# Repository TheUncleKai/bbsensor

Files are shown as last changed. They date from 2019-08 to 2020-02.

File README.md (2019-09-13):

# bbsensor
BBQ Sensor

The 8 is a simple temperature monitor intended for BBQ/Smoker. It has 8 inlets that can be used with PTC or Pt100 probes. The BBSensor is run by a ESP8266 Microcontroller (NodeMCU Lua Lolin V3 Modul). The temperature can be delivered either via the display or network.

Front view
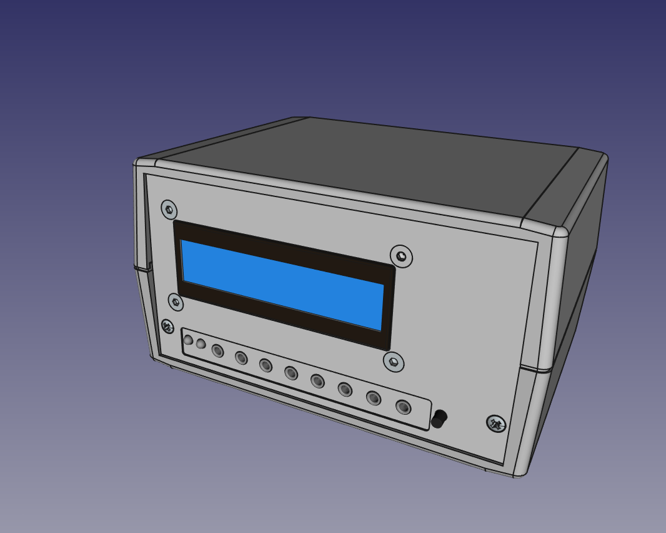
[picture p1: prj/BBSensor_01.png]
Main View


Back view
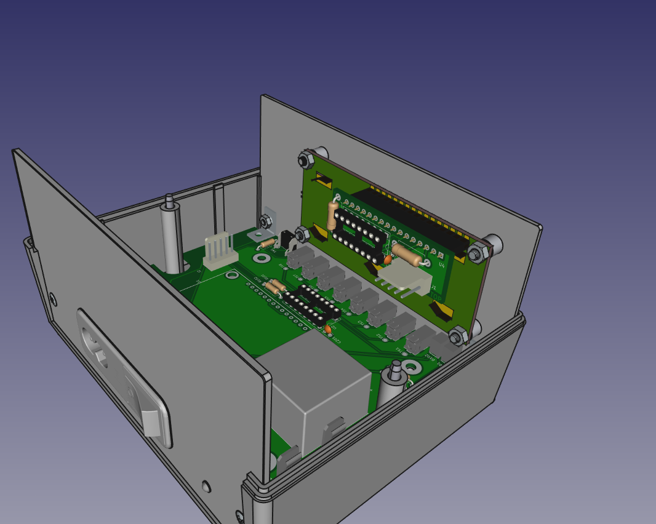
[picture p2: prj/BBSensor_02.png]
Back View


Top view
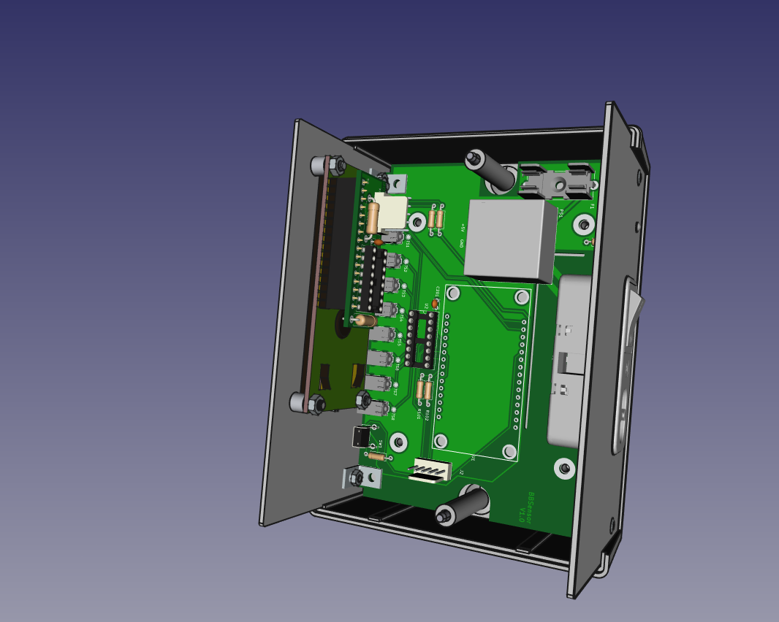
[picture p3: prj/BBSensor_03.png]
Top View


[view1]: prj/BBSensor_01.png
[view2]: prj/BBSensor_02.png
[view3]: prj/BBSensor_03.png

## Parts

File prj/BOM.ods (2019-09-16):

Project | Sourced | Placed | References | Value | Footprint | Quantity | Description | Quantity | Hersteller | Lfd. | Mouser | Price | Sum
 |  |  | R150, R151 | 140 | R_Axial_DIN0207_L6.3mm_D2.5mm_P10.16mm_Horizontal | 2 | Trimmer Resistors - Through Hole 3/8IN 500 OHM Sealed Horizontal Adjust | 12 | BOURNS | 3296Z-1-501LF | 652-3296Z-1-501LF | 2,170 € | 26,040 €
 |  |  | R8, R10 | 200 | R_Axial_DIN0207_L6.3mm_D2.5mm_P10.16mm_Horizontal | 2 | Trimmer Resistors - Through Hole 3/8" 1Mohms Sealed Horizontal Adjust | 12 | BOURNS | 3296Z-1-105LF | 652-3296Z-1-105LF | 2,170 € | 26,040 €
 |  |  | R1 | 220 | R_Axial_DIN0207_L6.3mm_D2.5mm_P10.16mm_Horizontal | 1 | Multilayer Ceramic Capacitors MLCC - Leaded 0.1uF 50volts 10% X7R 2.5mm LS | 0 | VISHAY | K104K15X7RF53L2 | 594-K104K15X7RF53L2 | 0,153 € | 0,000 €
 |  |  | R301 | 220 | R_Axial_DIN0411_L9.9mm_D3.6mm_P12.70mm_Horizontal | 1 | Analog to Digital Converters - ADC 12-bit SPI 8 Chl | 0 | MICROCHIP | MCP3208-CI/P | 579-MCP3208CIP | 3,220 € | 0,000 €
 |  |  | R2 | 300 | Potentiometer_Bourns_3296Z_Horizontal | 1 | Counter Shift Registers Tri-State 8-Bit | 0 | TI | SN74HC595N | 595-SN74HC595N | 0,477 € | 0,000 €
 |  |  | R1 | 405 | Potentiometer_Bourns_3296Z_Horizontal | 1 | Operational Amplifiers - Op Amps Single-Supply Rail-to-Rail | 6 | TI | OPA2340PAG4 | 595-OPA2340PA | 4,190 € | 25,140 €
 |  |  | R9 | 470 | Potentiometer_Bourns_3296Z_Horizontal | 1 | IC & Component Sockets STANDRD SOLDER TAIL DIP SOCKET (8 Pos) | 0 | Mill-Max | 115-47-308-41-001000 | 575-1154730841001000 | 0,414 € | 0,000 €
 |  |  | R2 | 100k | R_Axial_DIN0207_L6.3mm_D2.5mm_P10.16mm_Horizontal | 1 | IC & Component Sockets STANDRD SOLDER TAIL DIP SOCKET (16 Pos) | 0 | Mill-Max | 123-47-316-41-001000 | 575-1234731641001000 | 1,610 € | 0,000 €
 |  |  | C1 | 100n | C_Disc_D3.0mm_W2.0mm_P2.50mm | 1 | Fixed Terminal Blocks 3P 2.54mm 90DEG | 6 | PHOENIX | 1725669 | 651-1725669 | 2,230 € | 13,380 €
 |  |  | C201 | 100n | C_Disc_D3.4mm_W2.1mm_P2.50mm | 1 | Fixed Terminal Blocks 2P 2.54mm 90DEG | 6 | PHOENIX | 1725656 | 651-1725656 | 1,490 € | 8,940 €
 |  |  | C301 | 100n | C_Disc_D3.4mm_W2.1mm_P2.50mm | 1 | Headers & Wire Housings VERT PCB HDR 5P GOLD FRICTION LOCK | 0 | MOLEX | 22-11-2052 | 538-22-11-2052 | 0,747 € | 0,000 €
 |  |  | R1, R3 | 10k | R_Axial_DIN0207_L6.3mm_D2.5mm_P10.16mm_Horizontal | 2 | Headers & Wire Housings HSG 5P W/RAMP/RIBS | 0 | MOLEX | 22-01-3057 | 538-22-01-3057 | 0,234 € | 0,000 €
 |  |  | RV1 | 10k | Potentiometer_Bourns_3296Z_Horizontal | 1 | Headers & Wire Housings CRIMP TERM 22-30 TIN | 0 | MOLEX | 08-50-0114 | 538-08-50-0114 | 0,153 € | 0,000 €
 |  |  | R5, R6 | 10k | R_Axial_DIN0207_L6.3mm_D2.5mm_P10.16mm_Horizontal | 2 | Fuse Holder FUSE-HOLDER OGN | 0 | SCHURTER | 0031.8211 | 693-0031.8211 | 0,810 € | 0,000 €
 |  |  | R101 | 1k | R_Axial_DIN0207_L6.3mm_D2.5mm_P10.16mm_Horizontal | 1 | AC Power Entry Modules 2.5A C8 INLET PCB MT | 2 | SCHURTER | CMF1.1111.12 | 693-CMF1.1111.12 | 7,780 € | 15,560 €
 |  |  | R302 | 2k | R_Axial_DIN0411_L9.9mm_D3.6mm_P12.70mm_Horizontal | 1 | LED Circuit Board Indicators RED DIFFUSED RIGHT ANGLE | 16 | CML | 5600F1 | 607-5600F1 | 0,648 € | 10,368 €
 |  |  | R11 | 2k | R_Axial_DIN0207_L6.3mm_D2.5mm_P10.16mm_Horizontal | 1 | LED Circuit Board Indicators GREEN DIFFUSED RIGHT ANGLE | 16 | CML | 5600F5 | 607-5600F5 | 0,648 € | 10,368 €
 |  |  | R102, R153 | 2k2 | R_Axial_DIN0207_L6.3mm_D2.5mm_P10.16mm_Horizontal | 2 | Tactile Switches SWITCH TACTILE | 20 | C&K | PTS645VL83-2LFS | 611-PTS645VL832 | 0,279 € | 5,580 €
 |  |  | R4 | 2k2 | R_Axial_DIN0207_L6.3mm_D2.5mm_P10.16mm_Horizontal | 1 | Display Development Tools 16x2 Black on Green Char LCD w Backlight | 0 | MIDAS | MC21605C6W-SPTLYI-V2 | 992-LCD-16X2Y | 12,020 € | 0,000 €
 |  |  | R7 | 4k7 | R_Axial_DIN0207_L6.3mm_D2.5mm_P10.16mm_Horizontal | 1 | Slide Switches 3.5mm SP3T Vertical 2mm travel | 10 | ALPS | SSSS211900 | 688-SSSS211900 | 2,260 € | 22,600 €
 |  |  | U3 | 74HC595 | DIP-16_W7.62mm_Socket | 1 | AC/DC Power Modules 5W 12Vdc 416mA AC/DC Power module | 2 | TRACOPOWER | TMPS 05-112 | 495-TMPS05-112 | 16,380 € | 32,760 €
 |  |  | TH1, TH2, TH3, TH4, TH5, TH6, TH7, TH8 | AudioJack3 | LUMBERG_1501_05 | 8 |  |  | LUMBERG | 1501 05
 |  |  | J1 | Conn_01x03 | PinHeader_1x03_P2.54mm_Vertical | 1 |  |  |  |  |  |  | 196,776 €
 |  |  | J1 | Conn_01x03 | PinHeader_1x03_P2.54mm_Vertical | 1
 |  |  | J1 | Conn_01x05 | Molex_KK256_Pin_Header_Straight_1x05 | 1
 |  |  | J2 | Display | Molex_KK256_Pin_Header_Straight_1x05 | 1
 |  |  | U1 | ESP8266-12E_NodeMCU_Lolin | ESP8266-12E_NodeMCU_Lolin | 1
 |  |  | F1 | Fuse | Fuse_holder_20x5_22.5 | 1
 |  |  | D102 | GREEN | 5600F | 1
 |  |  | U4 | HD44780 | PinSocket_1x16_P2.54mm_Vertical | 1
 |  |  | U2 | MCP3208 | DIP-16_W7.62mm_Socket | 1
 |  |  | ~, ~, ~, ~ | Mounting_Bracket_L10_W7_M3 | Mounting_Bracket_L10_W7_M3 | 4
 |  |  | ~, ~ | MountingHole_2.7mm_M2.5 | MountingHole_2.7mm_M2.5 | 2
 |  |  | U1, U2 | OPA2340 | DIP-8_W7.62mm_Socket | 2
 |  |  | D1 | POWER | 5600F | 1
 |  |  | R3 | PT100 | TerminalBlock_Pheonix_MPT-2.54mm_2pol | 1
 |  |  | D101 | RED | 5600F | 1
 |  |  | J1 | Schurter_CMF1 | CMF1_Offset | 1
 |  |  | SW1 | SW_Push | SW_Tactile_SPST_Angled_PTS645Vx83-2LFS | 1
 |  |  | SW1 | SW_SP3T | ALPS_SSSS211900 | 1
 |  |  | TH1 | Thermistor_PTC | PinHeader_1x02_P2.54mm_Vertical | 1
 |  |  | PS1 | TMPS_05 | Traco_TMPS_05 | 1

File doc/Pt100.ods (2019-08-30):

Nennwiderstand: | 100 | Ohm | R0 |  | Über 0°C: | 0,003908300000000 | a
 |  |  |  |  |  | -0,000000577500000 | b | über 0°C: R=R0*(1+a*T+b*T^2) a= 3,9083*10^-3 /K b= -5,775*10^-7 /K^2 Unter 0°C: R=R0*(1+a*T+b*T^2+c*(T-100)*T^3) a= 3,9083*10^-3 b= -5,775*10^-7 c= -4,183*10^-12
Untere Spannung Ua0: | 0 | V | Umin
Obere Spannung (Ua100): | 5 | V | Umax |  | Unter 0°C: | -0,000000000004183 | c
Minimale Temperatur: | 0 | °C | Tmin
Maximale Temperatur: | 500 | °C | Tmax |  | 150
Rmin: | 100,00 | Ohm | Rmin
Rmax: | 280,98 | Ohm | Rmax |  | 157,33
Uref: | 5 | V | Uref
Messstrom: | 1 | mA | I
dU0: | 0,100 | V | dUmin
dU100: | 0,281 | V | dUmax
R2: | 300 | Ohm | R2
R4: | 2200 | Ohm | R4
U1: | 2,5 | V
k2: | 1,0825 |  | k2
k1: | 25,5226 |  | k1
R10: | 200 | Ohm | R10
R9+R11: | 2424,8 | Ohm | 2000 | 470 | 424,8269254746
R8: | 200 | Ohm | R8
R7+R1: | 5104,5 | Ohm | 4700 |  | 404,5268058184
R1 | 405 | Ohm
R2 | 300 | Ohm
R3 | 281 | Ohm
R4 | 2200 | Ohm
R5 | 10000 | Ohm
R6 | 10000 | Ohm
R7 | 4700 | Ohm
R8 | 200 | Ohm
R9 | 2000 | Ohm
R10 | 200 | Ohm
R11 | 470 | Ohm

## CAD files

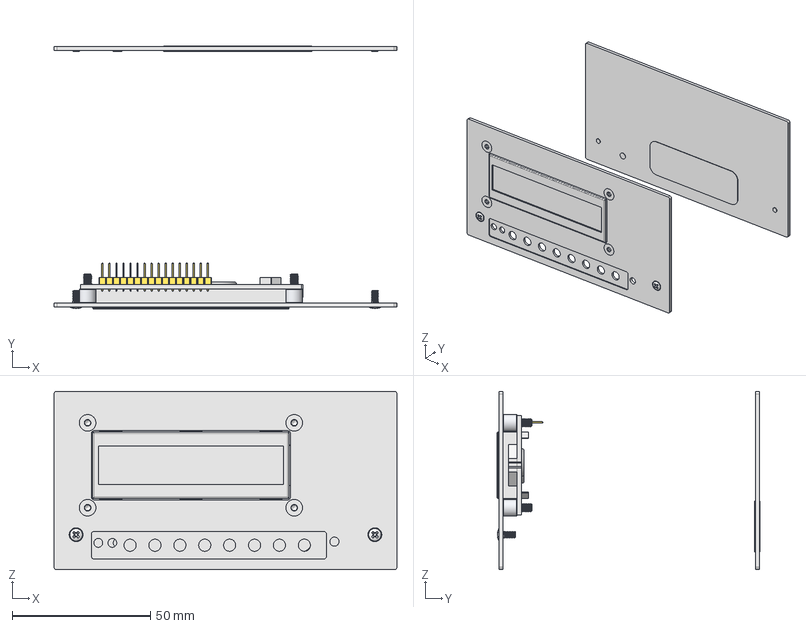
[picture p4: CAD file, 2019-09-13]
hardware/Mini/cad/BBMini.FCStd
124.0 x 95.2 x 64.5 mm
Panel Front
Pin_Strip
HD44780_LCD_2x16
Display_Spacer
Display_Screw_001
Display_Screw_002
Display_Screw_003
Display_Screw_004
Front_001
Front_002
Panel_Plate_2

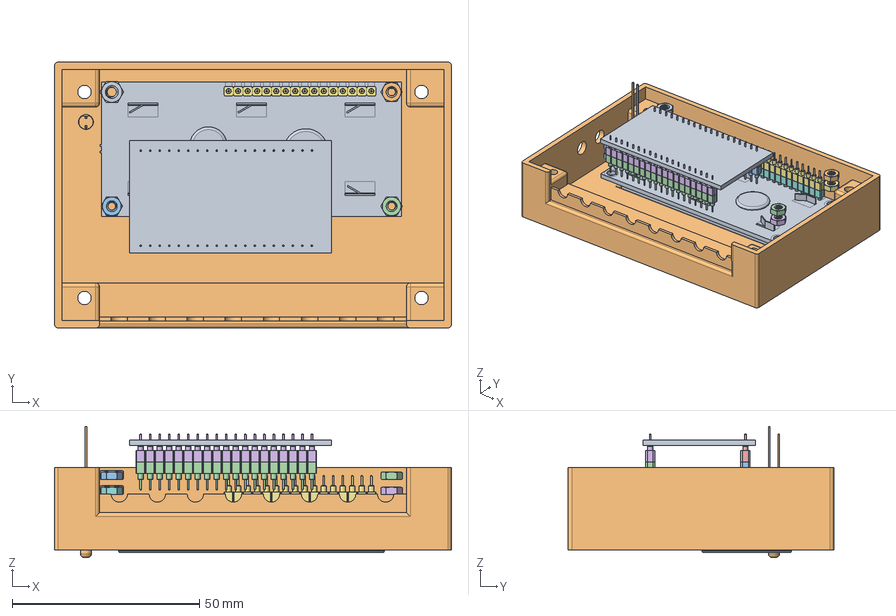
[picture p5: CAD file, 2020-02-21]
hardware/Mini32/cad/Mini32.FCStd
106.0 x 71.0 x 35.0 mm
ISO4032_M2.5_001
ISO4032_M2.5_002
ISO4032_M2.5_003
ISO4032_M2.5_004
ISO4032_M2.5_005
ISO4032_M2.5_006
ISO4032_M2.5_007
ISO4032_M2.5_008
HD44780_LCD_2x16
Standard_LED_3 mm_Green
Precision_Socket_Strip_Straight_L3.0_P2.5_01x19_001
Precision_Socket_Strip_Straight_L3.0_P2.5_01x19_002
Precision_Pin_Strip_Straight_L3.0_P2.5_01x19_001
Precision_Pin_Strip_Straight_L3.0_P2.5_01x19_002
Precision_Socket_Strip_Straight_L3.0_P2.5_01x16
Precision_Pin_Strip_Straight_L3.0_P2.5_01x16
Case

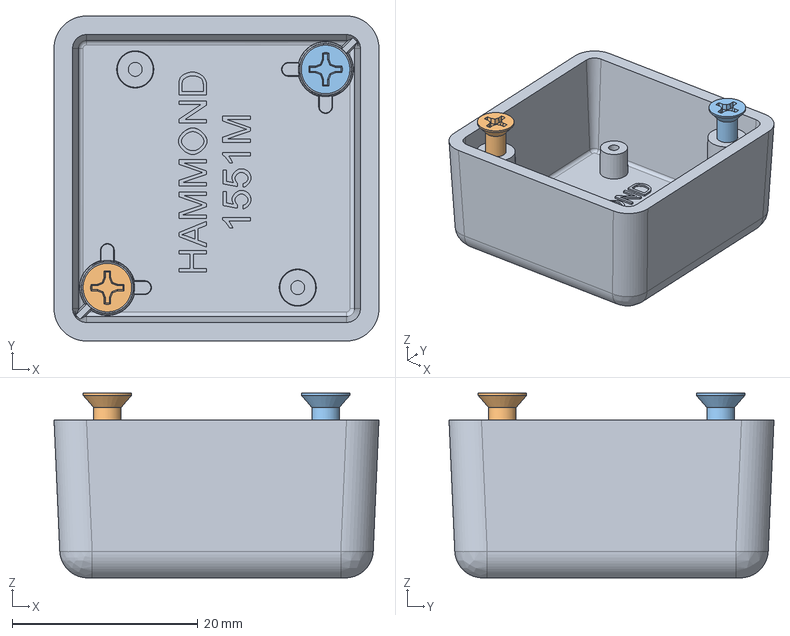
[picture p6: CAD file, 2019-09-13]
hardware/PTC/cad/RTC.FCStd
35.0 x 35.0 x 19.9 mm
1551M Box
SC510 (screw #4X 1_2' FH)
SC510 (screw #4X 1_2' FH)001

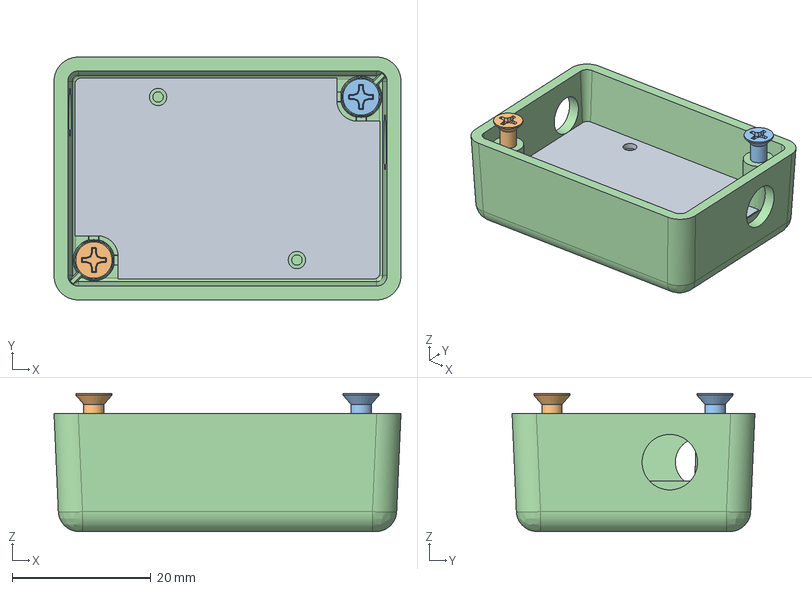
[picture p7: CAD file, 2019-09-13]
hardware/RTD/cad/RTD.FCStd
50.0 x 35.0 x 19.9 mm
1551G PCB
SC510 (screw #4X 1_2' FH)
SC510 (screw #4X 1_2' FH)001

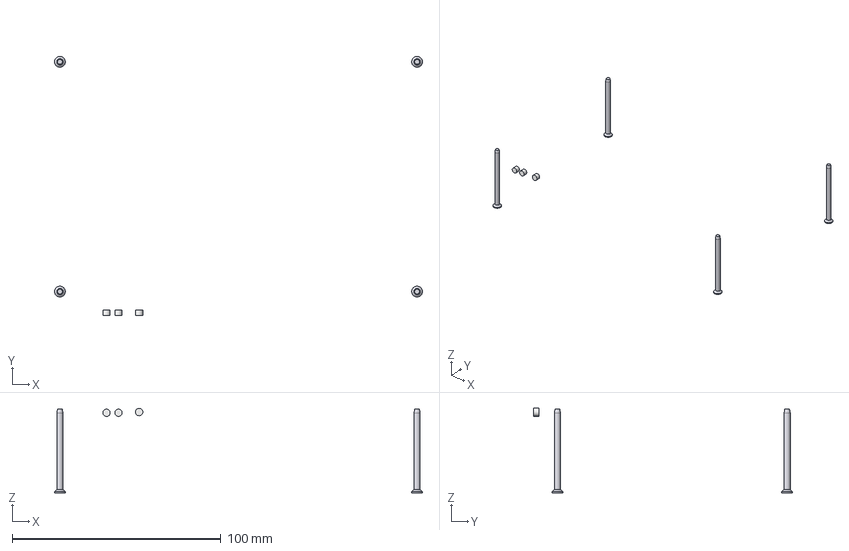
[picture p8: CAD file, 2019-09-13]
hardware/Sensor/cad/BBSensor.FCStd
176.2 x 124.1 x 40.5 mm
Cross Recessed Flat Countersunk Head Tapping Screw - Type F - Type I - Metric M3x0.5 x 16
Cross Recessed Flat Countersunk Head Tapping Screw - Type F - Type I - Metric M3x0.5 x 017
Cross Recessed Flat Countersunk Head Tapping Screw - Type F - Type I - Metric M3x0.5 x 018
Cross Recessed Flat Countersunk Head Tapping Screw - Type F - Type I - Metric M3x0.5 x 019

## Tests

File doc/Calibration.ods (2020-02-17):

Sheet: Test Sensor
[°C] | [n] | [°C] | [n] | [°C] | [n] | [°C] | [n]
100 |  | 74 |  | 48 |  | 22
99 |  | 73 |  | 47 |  | 21
98 |  | 72 |  | 46 |  | 20
97 |  | 71 |  | 45 |  | 19
96 |  | 70 |  | 44 |  | 18
95 |  | 69 |  | 43 |  | 17
94 |  | 68 |  | 42 |  | 16
93 |  | 67 |  | 41 |  | 15
92 |  | 66 |  | 40 |  | 14
91 |  | 65 |  | 39 |  | 13
90 |  | 64 |  | 38 |  | 12
89 |  | 63 |  | 37 |  | 11
88 |  | 62 |  | 36 |  | 10
87 |  | 61 |  | 35 |  | 9
86 |  | 60 |  | 34 |  | 8
85 |  | 59 |  | 33 |  | 7
84 |  | 58 |  | 32 |  | 6
83 |  | 57 |  | 31 |  | 5
82 |  | 56 |  | 30 |  | 4
81 |  | 55 |  | 29 |  | 3
80 |  | 54 |  | 28 |  | 2
79 |  | 53 |  | 27 |  | 1
78 |  | 52 |  | 26 |  | 0
77 |  | 51 |  | 25 |  | -1
76 |  | 50 |  | 24 |  | -2
75 |  | 49 |  | 23 |  | -3
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

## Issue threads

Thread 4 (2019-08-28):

Firmware: Read temperatures

TheUncleKai, 2019-08-28:
Read sensor data from ADC and convert to temperatures

TheUncleKai, 2019-11-10:
Issue is done.

Closed 2019-11-10.

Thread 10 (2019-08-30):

Bug fixes

TheUncleKai, 2019-08-30:
General bug fixes and tweaks of PCB and Schematics.

Closed 2020-02-19.

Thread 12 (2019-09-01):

Firmware: Make basics work

TheUncleKai, 2019-09-01:
Make basics like button input and LEDs work.

TheUncleKai, 2019-09-23:
Issue is done.

Closed 2019-09-23.

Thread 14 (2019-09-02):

General PCB improvements

TheUncleKai, 2019-09-02:
General PCB improvements (shrink, small fixes, etc.).

Closed 2020-02-19.

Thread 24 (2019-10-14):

Version 3: Experimental PCB with only one ADC and multiplexer

TheUncleKai, 2019-10-14:
Replace MCP3208 with a single ADC and a 16 to 2 channel multiplexer.

Closed 2020-02-19.

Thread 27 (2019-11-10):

Firmware: Convert Temperatures

TheUncleKai, 2019-11-10:
Convert ADC values to correct temperatures.

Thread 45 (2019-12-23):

Firmware: Replace Hardware class

TheUncleKai, 2019-12-23:
Replace Hardware class with simple executor, make all devices in main.cpp.

Closed 2020-02-19.

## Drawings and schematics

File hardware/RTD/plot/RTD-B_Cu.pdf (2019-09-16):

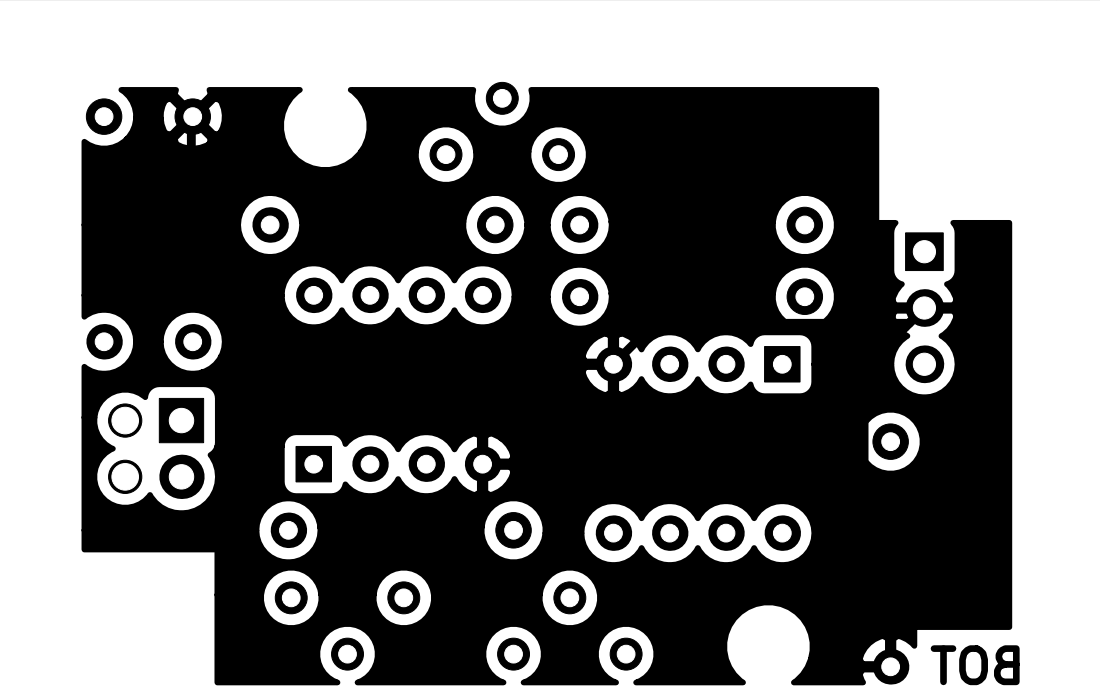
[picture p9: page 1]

File: RTD.kicad_pcb Sheet: Amplifier for Pt100 sensors

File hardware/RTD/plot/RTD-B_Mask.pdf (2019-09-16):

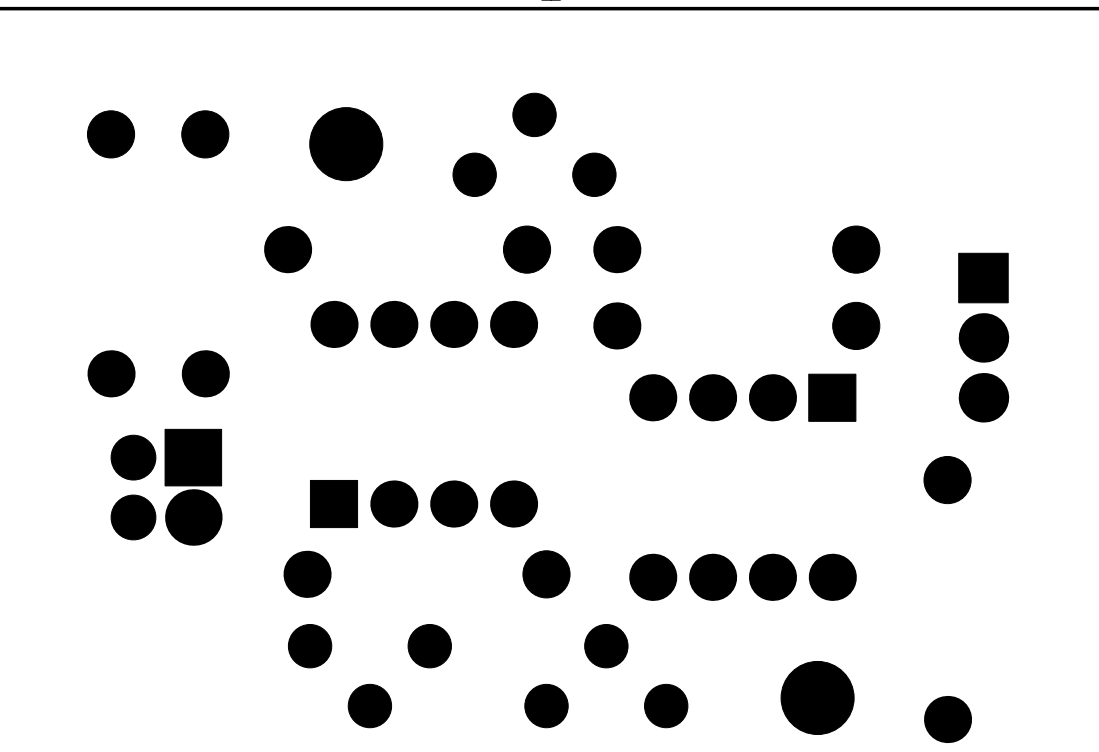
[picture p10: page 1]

File: RTD.kicad_pcb Sheet: Amplifier for Pt100 sensors

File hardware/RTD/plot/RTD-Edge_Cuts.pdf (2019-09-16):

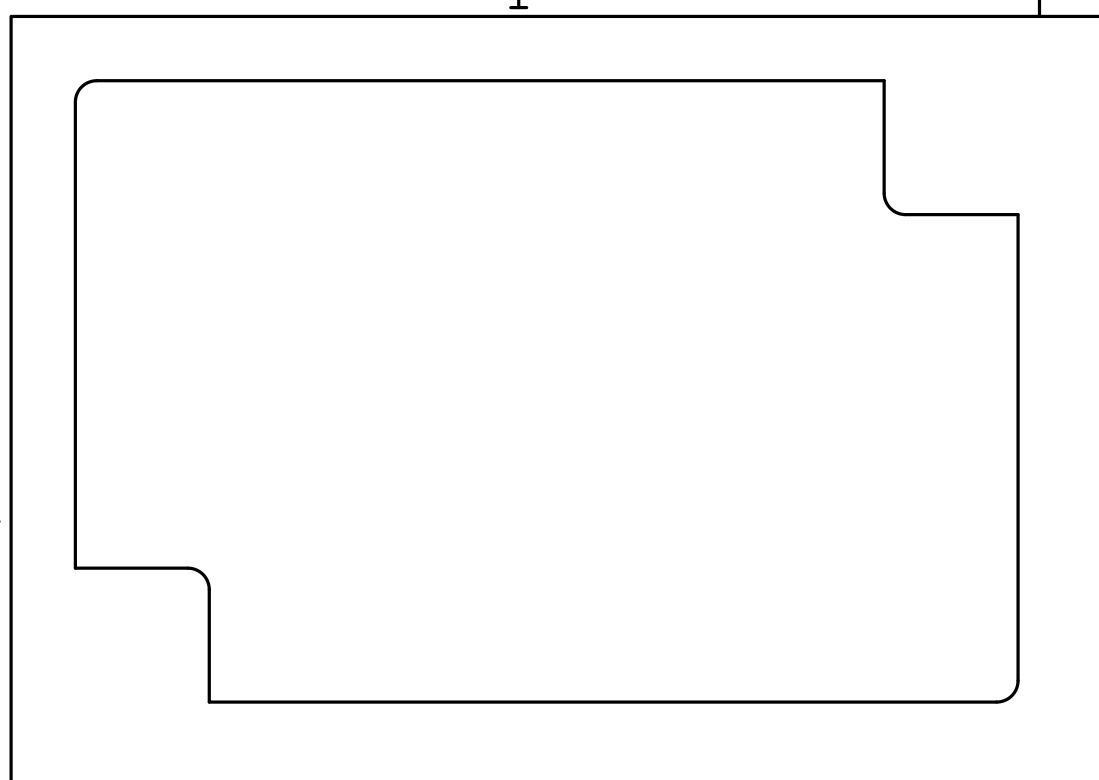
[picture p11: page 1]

File: RTD.kicad_pcb Sheet: Amplifier for Pt100 sensors

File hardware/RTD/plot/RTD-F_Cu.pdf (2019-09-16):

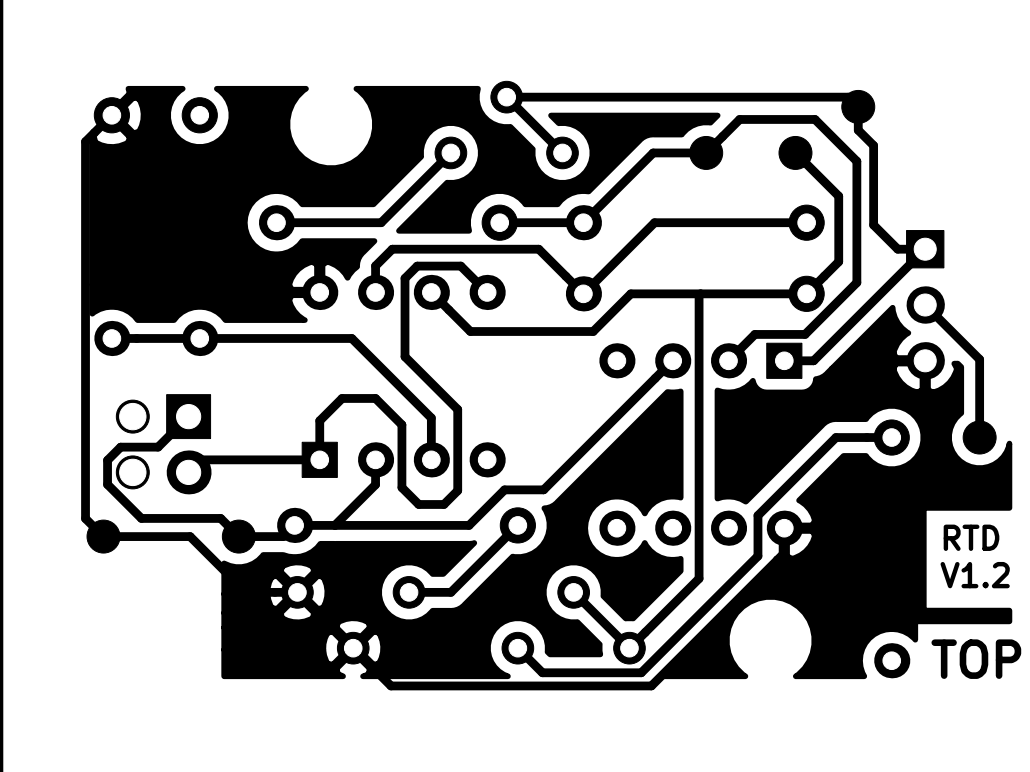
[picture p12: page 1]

File: RTD.kicad_pcb Sheet: Amplifier for Pt100 sensors

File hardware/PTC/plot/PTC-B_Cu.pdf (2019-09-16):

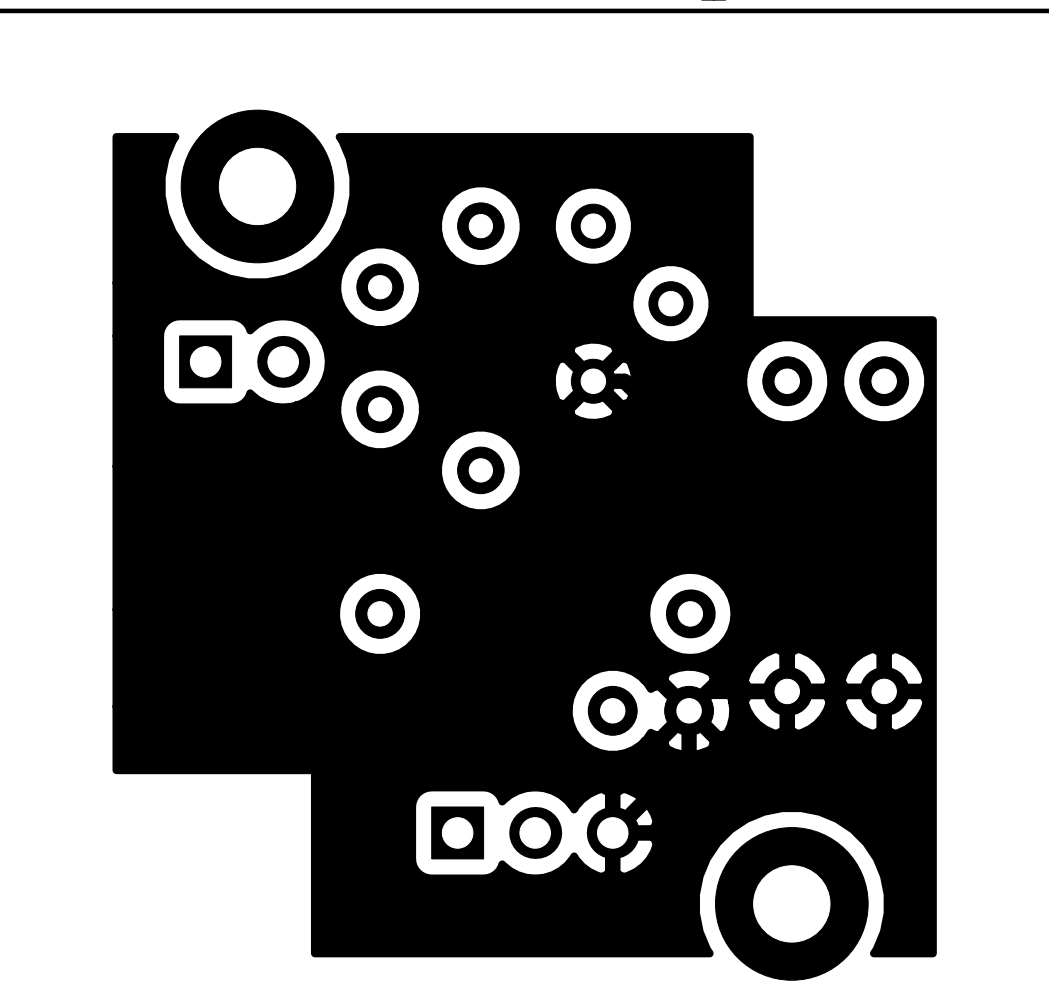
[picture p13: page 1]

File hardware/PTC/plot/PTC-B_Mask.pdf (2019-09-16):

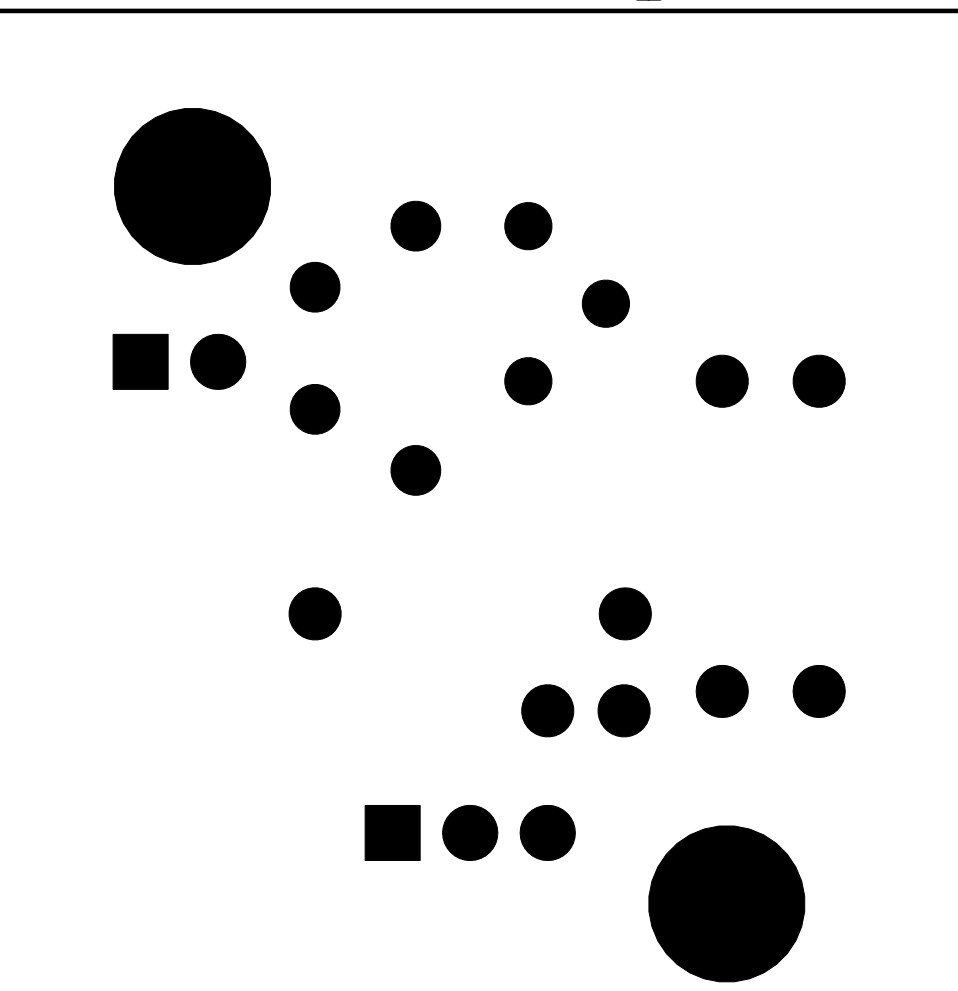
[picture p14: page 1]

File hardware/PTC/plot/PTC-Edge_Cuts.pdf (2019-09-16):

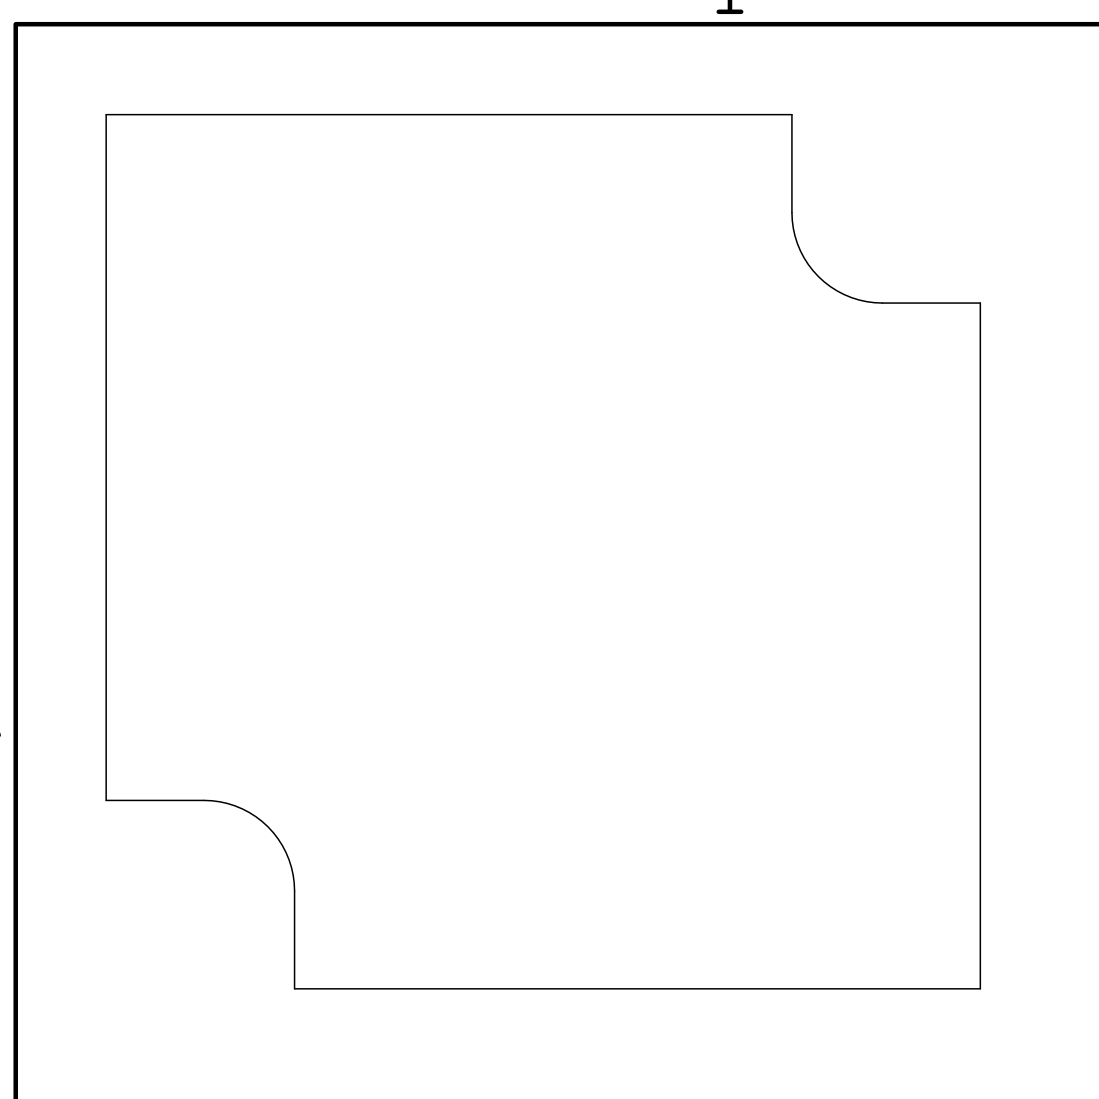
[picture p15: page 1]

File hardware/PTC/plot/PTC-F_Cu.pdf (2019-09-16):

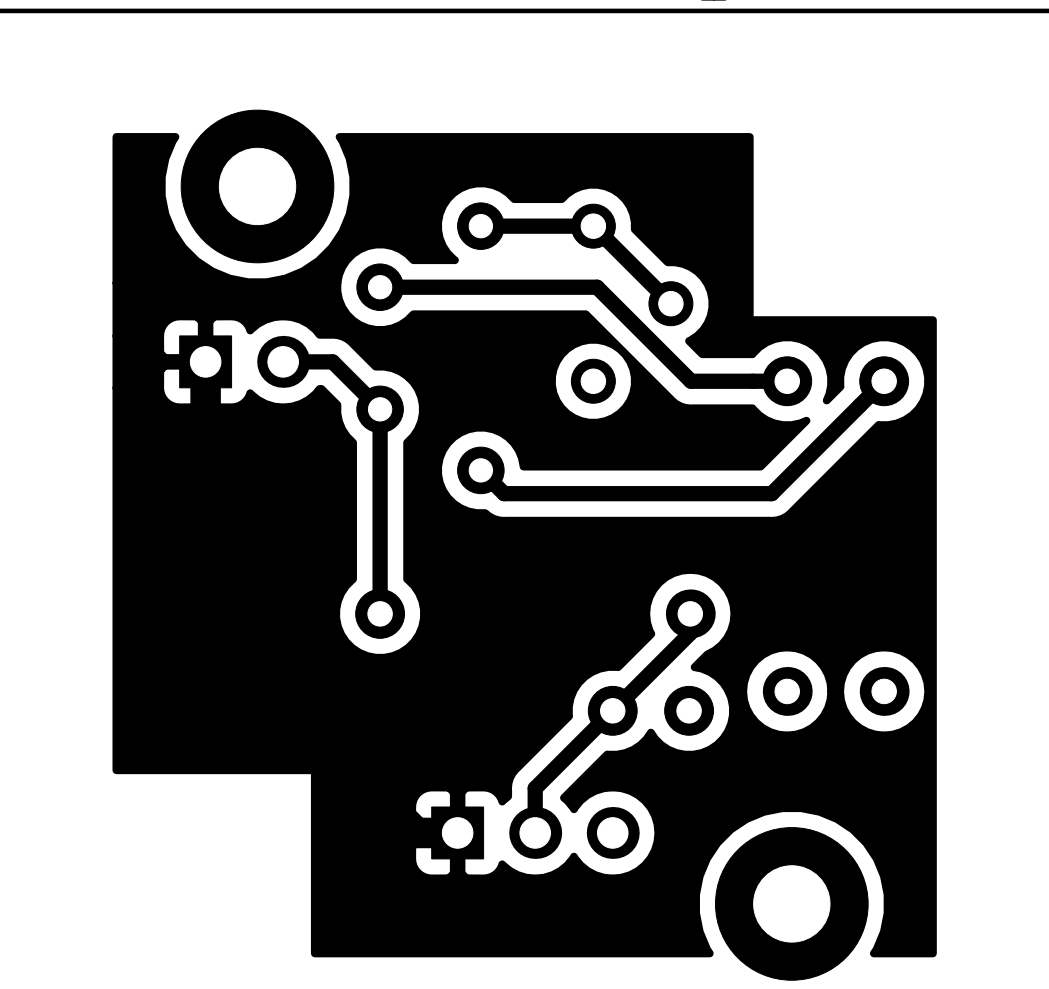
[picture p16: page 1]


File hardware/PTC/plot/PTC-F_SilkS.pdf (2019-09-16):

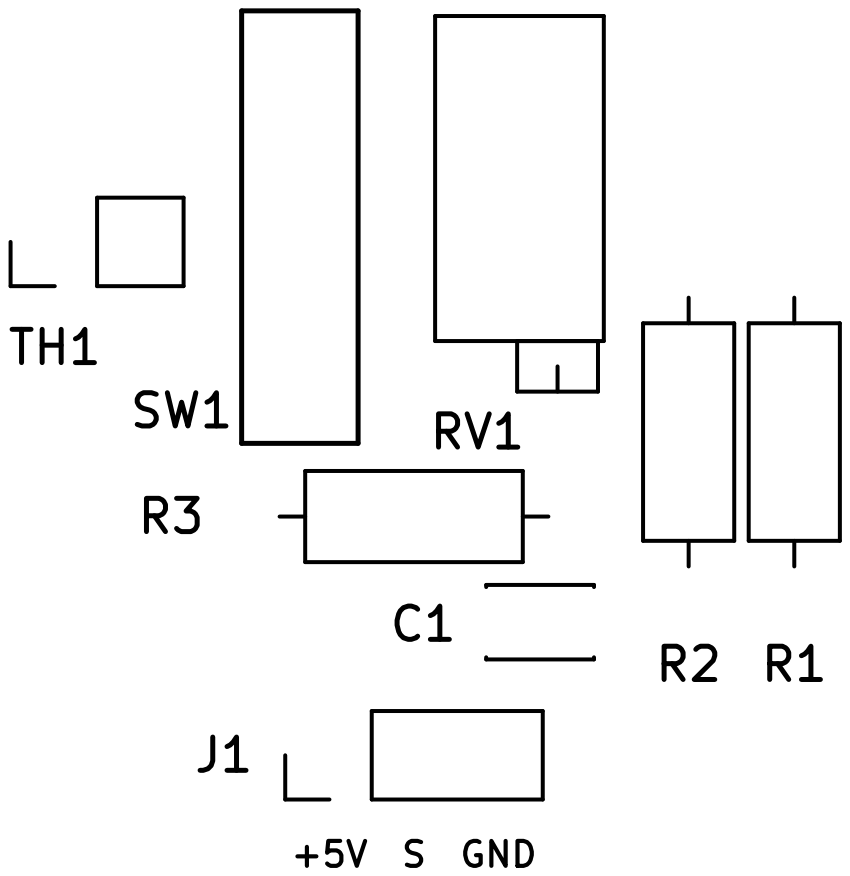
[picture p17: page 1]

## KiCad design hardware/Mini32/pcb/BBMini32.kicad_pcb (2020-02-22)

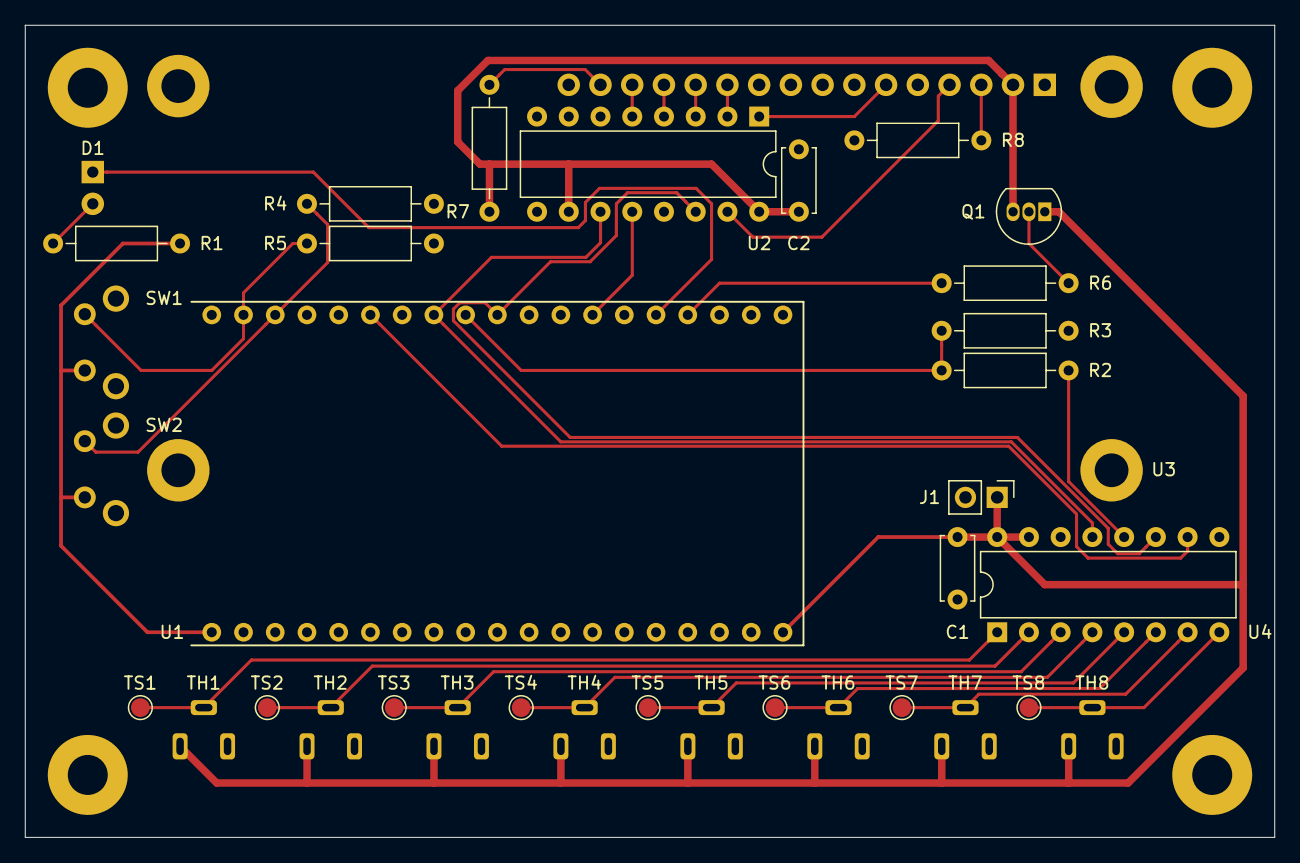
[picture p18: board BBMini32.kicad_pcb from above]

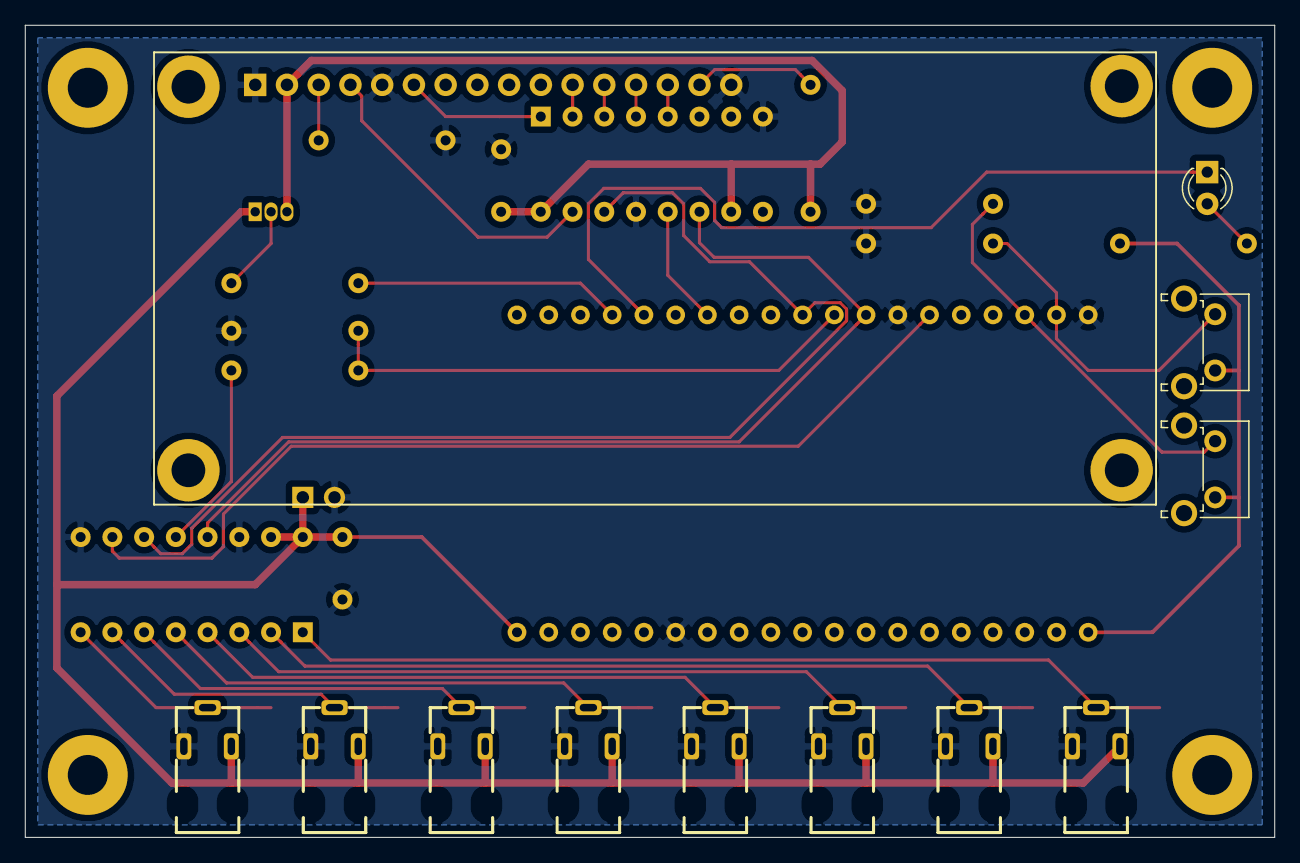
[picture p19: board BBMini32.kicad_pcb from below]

Board: 2 copper layers, 100.0 x 65.0 mm, 35 parts (12 on the bottom side), 32 nets.

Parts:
C1, C2: 100n; C_Disc_D5.0mm_W2.5mm_P5.00mm
D1: GREEN; LED_D3.0mm
J1: POWER; PinHeader_1x02_P2.54mm_Vertical
Q1: S8550; TO-92_Inline
R1: 140; R_Axial_DIN0207_L6.3mm_D2.5mm_P10.16mm_Horizontal
R2: 1k; R_Axial_DIN0207_L6.3mm_D2.5mm_P10.16mm_Horizontal
R3, R4, R5, R6: 2k2; R_Axial_DIN0207_L6.3mm_D2.5mm_P10.16mm_Horizontal
R7: 220; R_Axial_DIN0207_L6.3mm_D2.5mm_P10.16mm_Horizontal
R8: 2k; R_Axial_DIN0207_L6.3mm_D2.5mm_P10.16mm_Horizontal
SW1, SW2: SW_Push; SW_Tactile_SPST_Angled_PTS645Vx31-2LFS
TH1, TH2, TH3, TH4, TH5, TH6, TH7, TH8: AudioJack3; LUMBERG_1501_05
TS1, TS2, TS3, TS4, TS5, TS6, TS7, TS8: TestPoint; TestPoint_Pad_D1.5mm
U1: ESP-32_NodeMCU
U2: 74HC595; DIP-16_W7.62mm
U3: HD44780; HD44780_LCD_2x16
U4: MCP3208; DIP-16_W7.62mm

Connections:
+3V3: R1.1, SW1.2, SW2.2, U1.1
+5V: C1.1, J1.1, Q1.1, TH1.R, TH2.R, TH3.R, TH4.R, TH5.R, TH6.R, TH7.R, TH8.R, U1.19, U4.15, U4.16
/CS1: U1.25, U4.10
/CS2: U1.32, U2.12
/DB4: U2.2, U3.11
/DB5: U2.3, U3.12
/DB6: U2.4, U3.13
/DB7: U2.5, U3.14
/ENABLE: U2.1, U3.6
/MISO: R2.1, U4.12
/MISO_5V: R2.2, R3.1, U1.28
/MOSI: U1.29, U2.14, U4.11
/RS: U2.15, U3.4
/SCLK: U1.27, U2.11, U4.13
/SIGNAL1: TH1.T, TS1.1, U4.1
/SIGNAL2: TH2.T, TS2.1, U4.2
/SIGNAL3: TH3.T, TS3.1, U4.3
/SIGNAL4: TH4.T, TS4.1, U4.4
/SIGNAL5: TH5.T, TS5.1, U4.5
/SIGNAL6: TH6.T, TS6.1, U4.6
/SIGNAL7: TH7.T, TS7.1, U4.7
/SIGNAL8: TH8.T, TS8.1, U4.8
/VDISP: C2.1, Q1.3, R7.1, U2.10, U2.16, U3.2
GND: C1.2, C2.2, J1.2, R3.2, R4.2, R5.2, R8.2, TH1.S, TH2.S, TH3.S, TH4.S, TH5.S, TH6.S, TH7.S, TH8.S, U1.14, U1.20, U1.26, U2.8, U2.13, U3.1, U3.5, U3.16, U4.9, U4.14
unnamed: D1.1, U1.34
unnamed: D1.2, R1.2
unnamed: Q1.2, R6.2
unnamed: R4.1, SW2.1, U1.22
unnamed: R5.1, SW1.1, U1.21
unnamed: R6.1, U1.35
unnamed: R7.2, U3.15
unnamed: R8.1, U3.3

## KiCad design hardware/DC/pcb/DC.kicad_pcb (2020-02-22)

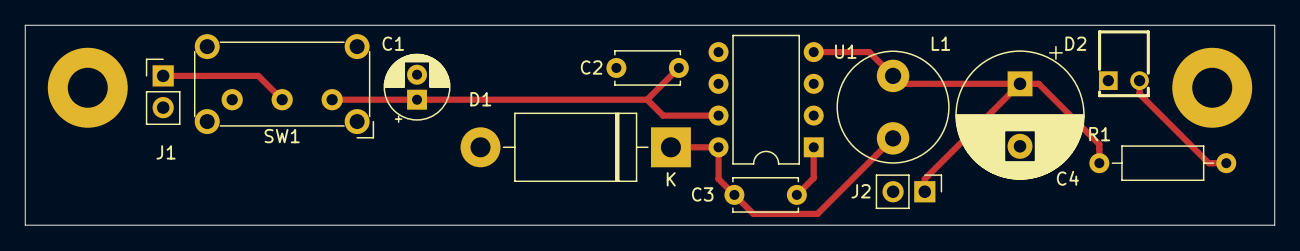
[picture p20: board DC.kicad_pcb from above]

Board: 2 copper layers, 100.0 x 16.0 mm, 12 parts (0 on the bottom side), 7 nets.

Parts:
C1: 100u; CP_Radial_D5.0mm_P2.00mm
C2: 100n; C_Disc_D5.0mm_W2.5mm_P5.00mm
C3: 10n; C_Disc_D5.0mm_W2.5mm_P5.00mm
C4: 68u; CP_Radial_D10.0mm_P5.00mm
D1: 1N5822; D_DO-201AD_P15.24mm_Horizontal
D2: POWER; 5600F
J1: POWER; PinHeader_1x02_P2.54mm_Vertical
J2: OUTPUT; PinHeader_1x02_P2.54mm_Vertical
L1: 47u; L_Radial_D8.7mm_P5.00mm_Fastron_07HCP
R1: 220; R_Axial_DIN0207_L6.3mm_D2.5mm_P10.16mm_Horizontal
SW1: SW_SPDT; SW_E-Switch_EG1224_SPDT_Angled
U1: LM2672M-5.0; DIP-8_W7.62mm

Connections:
+5V: C4.1, J2.1, L1.2, R1.1, U1.4
/VIN: C1.1, C2.1, SW1.1, U1.7
/VPOWER: J1.1, SW1.2
GND: C1.2, C2.2, C4.2, D1.2, D2.1, J1.2, J2.2, U1.6
unnamed: C3.1, D1.1, L1.1, U1.8
unnamed: C3.2, U1.1
unnamed: D2.2, R1.2

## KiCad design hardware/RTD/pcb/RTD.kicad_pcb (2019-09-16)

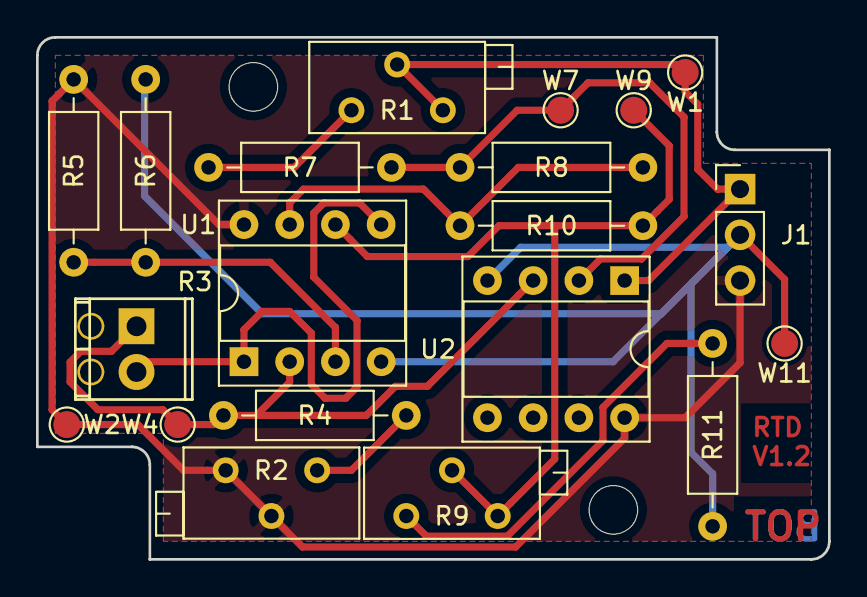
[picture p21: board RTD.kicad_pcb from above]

Board: 2 copper layers, 44.0 x 29.0 mm, 20 parts (0 on the bottom side), 12 nets.

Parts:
J1: Conn_01x03; PinHeader_1x03_P2.54mm_Vertical
R1: 405; Potentiometer_Bourns_3296Z_Horizontal
R2: 300; Potentiometer_Bourns_3296Z_Horizontal
R3: PT100; TerminalBlock_Pheonix_MPT-2.54mm_2pol
R4: 2k2; R_Axial_DIN0207_L6.3mm_D2.5mm_P10.16mm_Horizontal
R5, R6: 10k; R_Axial_DIN0207_L6.3mm_D2.5mm_P10.16mm_Horizontal
R7: 4k7; R_Axial_DIN0207_L6.3mm_D2.5mm_P10.16mm_Horizontal
R8, R10: 200; R_Axial_DIN0207_L6.3mm_D2.5mm_P10.16mm_Horizontal
R9: 470; Potentiometer_Bourns_3296Z_Horizontal
R11: 2k; R_Axial_DIN0207_L6.3mm_D2.5mm_P10.16mm_Horizontal
U1, U2: OPA2340; DIP-8_W7.62mm_Socket
W1, W2, W4, W7, W9, W11: TestPoint_Pad_D1.5mm

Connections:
+5V: J1.3, R2.2, R2.3, R5.1, U1.8, U2.8, W2.1
/SIGNAL: J1.1, R1.2, R1.3, U2.1, W1.1
GND: J1.2, R6.1, R11.2, U1.4, U2.4, W11.1
unnamed: R1.1, R7.2
unnamed: R2.1, R4.1
unnamed: R3.1, R4.2, U1.2, U2.3, W4.1
unnamed: R3.2, U1.1, U1.5
unnamed: R5.2, R6.2, U1.3
unnamed: R7.1, R8.2, U2.2, W7.1
unnamed: R9.2, R9.3, R10.1, U1.6, W9.1
unnamed: R8.1, R10.2, U1.7
unnamed: R9.1, R11.1

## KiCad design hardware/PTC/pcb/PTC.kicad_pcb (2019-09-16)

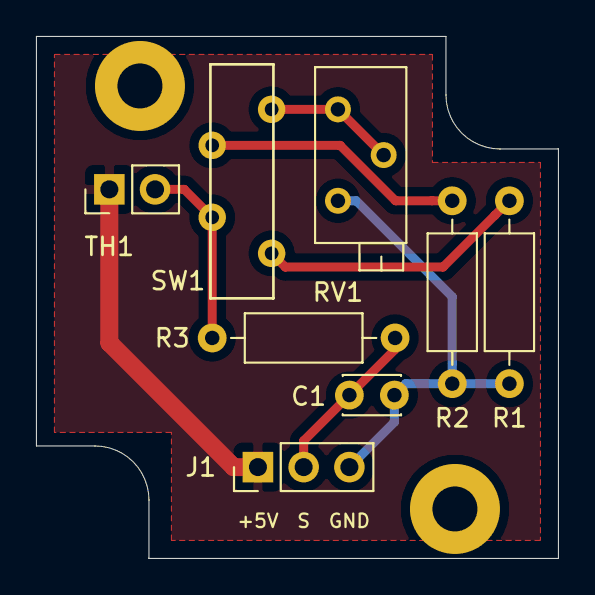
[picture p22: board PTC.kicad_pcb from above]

Board: 2 copper layers, 29.0 x 29.0 mm, 8 parts (0 on the bottom side), 7 nets.

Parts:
C1: 100; C_Disc_D3.0mm_W2.0mm_P2.50mm
J1: Conn_01x03; PinHeader_1x03_P2.54mm_Vertical
R1, R3: 10k; R_Axial_DIN0207_L6.3mm_D2.5mm_P10.16mm_Horizontal
R2: 100k; R_Axial_DIN0207_L6.3mm_D2.5mm_P10.16mm_Horizontal
RV1: 10k; Potentiometer_Bourns_3296Z_Horizontal
SW1: SW_SP3T; ALPS_SSSS211900
TH1: Thermistor_PTC; PinHeader_1x02_P2.54mm_Vertical

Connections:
+5V: J1.1, TH1.1
/SIGNAL: C1.1, J1.2, R3.2
GND: C1.2, J1.3, R1.2, R2.2, RV1.3
unnamed: R1.1, SW1.4
unnamed: R2.1, SW1.2
unnamed: R3.1, SW1.3, TH1.2
unnamed: RV1.1, RV1.2, SW1.1

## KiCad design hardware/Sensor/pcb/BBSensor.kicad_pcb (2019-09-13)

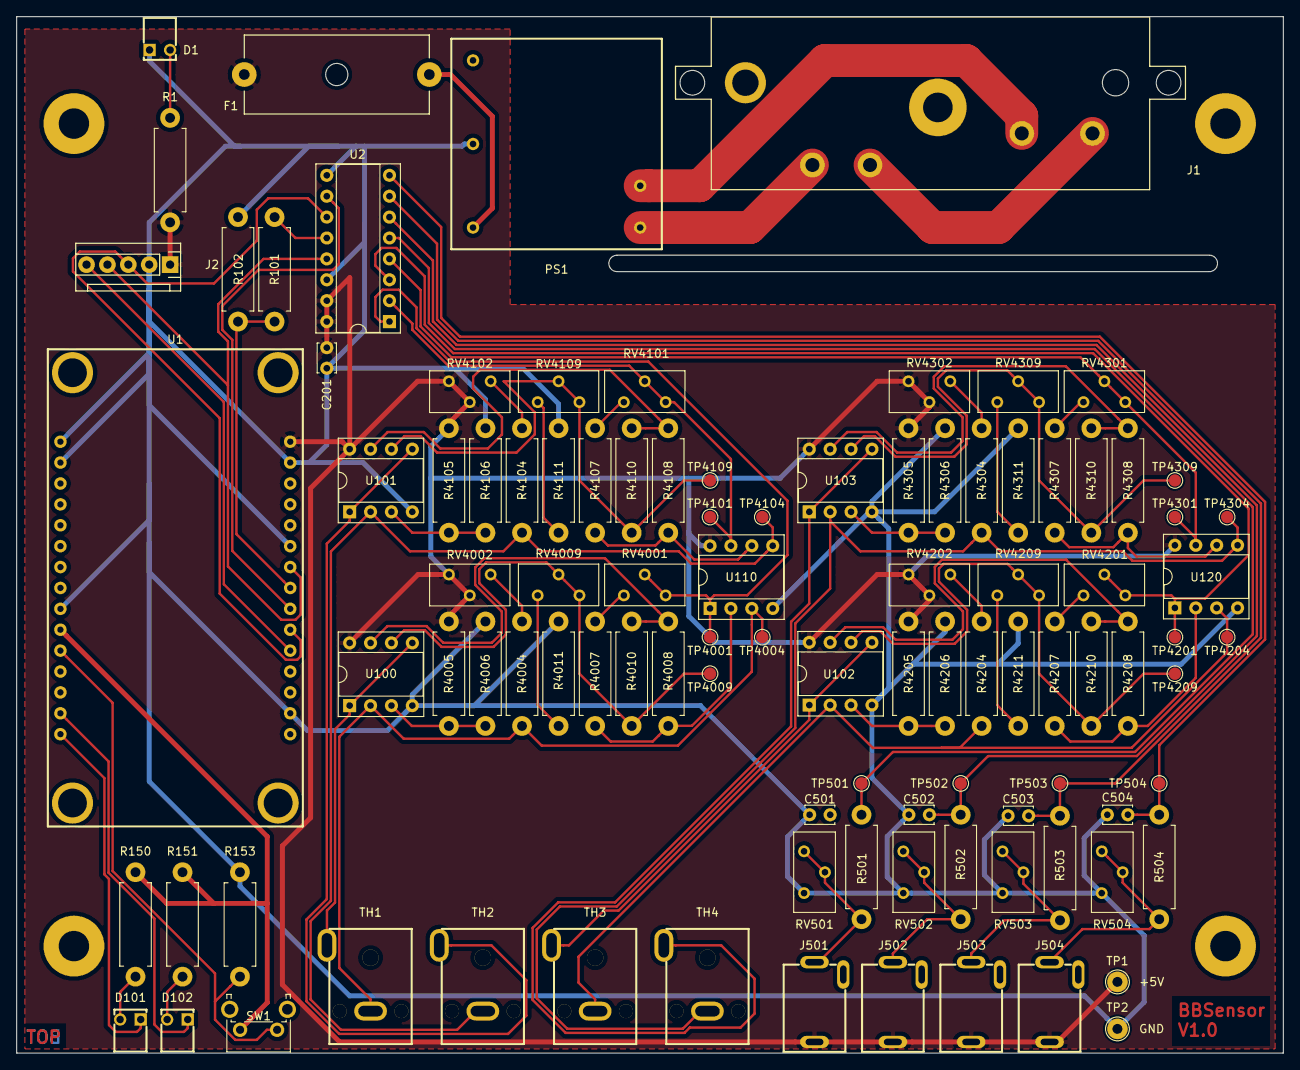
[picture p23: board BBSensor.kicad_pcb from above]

Board: 2 copper layers, 154.0 x 126.0 mm, 101 parts (0 on the bottom side), 67 nets.

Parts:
C201, C501, C502, C503, C504: 100n; C_Disc_D3.4mm_W2.1mm_P2.50mm
D1: POWER; 5600F
D101: RED; 5600F
D102: GREEN; 5600F
F1: Fuse; Fuse_holder_20x5_22.5
J1: Schurter_CMF1; CMF1
J2: Display; Molex_KK256_Pin_Header_Straight_1x05
J501, J502, J503, J504: AudioJack2_SwitchT; LUMBERG_1501_09
PS1: TMPS_05; Traco_TMPS_05
R1: 220; R_Axial_DIN0411_L9.9mm_D3.6mm_P12.70mm_Horizontal
R101: 1k; R_Axial_DIN0411_L9.9mm_D3.6mm_P12.70mm_Horizontal
R102, R153, R4004, R4104, R4204, R4304: 2k2; R_Axial_DIN0411_L9.9mm_D3.6mm_P12.70mm_Horizontal
R150, R151: 140; R_Axial_DIN0411_L9.9mm_D3.6mm_P12.70mm_Horizontal
R501, R502, R503, R504, R4005, R4006, R4105, R4106, R4205, R4206, R4305, R4306: 10k; R_Axial_DIN0411_L9.9mm_D3.6mm_P12.70mm_Horizontal
R4007, R4107, R4207, R4307: 4k7; R_Axial_DIN0411_L9.9mm_D3.6mm_P12.70mm_Horizontal
R4008, R4010, R4108, R4110, R4208, R4210, R4308, R4310: 200; R_Axial_DIN0411_L9.9mm_D3.6mm_P12.70mm_Horizontal
R4011, R4111, R4211, R4311: 2k; R_Axial_DIN0411_L9.9mm_D3.6mm_P12.70mm_Horizontal
RV501, RV502, RV503, RV504: 10k; Potentiometer_Bourns_3296Y_Vertical
RV4001, RV4101, RV4201, RV4301: 405; Potentiometer_Bourns_3296Y_Vertical
RV4002, RV4102, RV4202, RV4302: 300; Potentiometer_Bourns_3296Y_Vertical
RV4009, RV4109, RV4209, RV4309: 470; Potentiometer_Bourns_3296Y_Vertical
SW1: SW_Push; SW_Tactile_SPST_Angled_PTS645Vx83-2LFS
TH1, TH2, TH3, TH4: Thermistor_NTC; LUMBERG_1553_02
TP1, TP2: TestPoint; TestPoint_THTPad_D2.5mm_Drill1.2mm
TP501, TP502, TP503, TP504, TP4001, TP4004, TP4009, TP4101, TP4104, TP4109, TP4201, TP4204, TP4209, TP4301, TP4304, TP4309: TestPoint; TestPoint_Pad_D1.5mm
U1: ESP8266-12E_NodeMCU_Lolin
U2: MCP3208; DIP-16_W7.62mm_Socket
U100, U101, U102, U103, U110, U120: OPA2340; DIP-8_W7.62mm_Socket

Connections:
+3V3: R150.1, R151.1, SW1.2, U1.21
+5V: C201.1, F1.1, J2.1, J501.S, J502.S, J503.S, J504.S, R1.2, R4005.2, R4105.2, R4205.2, R4305.2, RV4002.2, RV4002.3, RV4102.2, RV4102.3, RV4202.2, RV4202.3, RV4302.2, RV4302.3, TP1.1, U1.15, U2.15, U2.16, U100.8, U101.8, U102.8, U103.8, U110.8, U120.8
/Analog/Digital/SPI1: J2.3, U1.6, U2.11
/Analog/Digital/SPI2: R101.2, U2.12
/Analog/Digital/SPI3: J2.4, U1.9, U2.13
/Analog/Digital/SPI4: U1.7, U2.10
/Analog/Digital/TEMP1: RV4001.2, RV4001.3, TP4001.1, U2.1, U110.1
/Analog/Digital/TEMP2: RV4101.2, RV4101.3, TP4101.1, U2.2, U110.7
/Analog/Digital/TEMP3: RV4201.2, RV4201.3, TP4201.1, U2.3, U120.1
/Analog/Digital/TEMP4: RV4301.2, RV4301.3, TP4301.1, U2.4, U120.7
/Analog/Digital/TEMP5: C501.1, R501.1, TP501.1, U2.5
/Analog/Digital/TEMP6: C502.1, R502.1, TP502.1, U2.6
/Analog/Digital/TEMP7: C503.1, R503.1, TP503.1, U2.7
/Analog/Digital/TEMP8: C504.1, R504.1, TP504.1, U2.8
/Display/SPI5: J2.5, U1.5
/ESP8266/MISO: R101.1, R102.1, U1.8
GND: C201.2, C501.2, C502.2, C503.2, C504.2, D1.1, J2.2, PS1.4, R102.2, R153.2, R4006.1, R4011.2, R4106.1, R4111.2, R4206.1, R4211.2, R4306.1, R4311.2, RV501.3, RV502.3, RV503.3, RV504.3, TP2.1, U1.2, U1.10, U1.14, U1.22, U1.29, U1.30, U2.9, U2.14, U100.4, U101.4, U102.4, U103.4, U110.4, U120.4
unnamed: D1.2, R1.1
unnamed: D101.1, U1.16
unnamed: D101.2, R150.2
unnamed: D102.1, U1.17
unnamed: D102.2, R151.2
unnamed: F1.2, PS1.5
unnamed: J1.1, PS1.2
unnamed: J1.2, J1.4
unnamed: J1.3, PS1.1
unnamed: J501.T, R501.2, RV501.1, RV501.2
unnamed: J502.T, R502.2, RV502.1, RV502.2
unnamed: J503.T, R503.2, RV503.1, RV503.2
unnamed: J504.T, R504.2, RV504.1, RV504.2
unnamed: R153.1, SW1.1, U1.20
unnamed: R4004.1, TH1.2, TP4004.1, U100.2, U110.3
unnamed: R4004.2, RV4002.1
unnamed: R4005.1, R4006.2, U100.3
unnamed: R4007.1, RV4001.1
unnamed: R4007.2, R4008.1, U110.2
unnamed: R4008.2, R4010.1, U100.7
unnamed: R4010.2, RV4009.2, RV4009.3, TP4009.1, U100.6
unnamed: R4011.1, RV4009.1
unnamed: R4104.1, TH2.2, TP4104.1, U101.2, U110.5
unnamed: R4104.2, RV4102.1
unnamed: R4105.1, R4106.2, U101.3
unnamed: R4107.1, RV4101.1
unnamed: R4107.2, R4108.1, U110.6
unnamed: R4108.2, R4110.1, U101.7
unnamed: R4110.2, RV4109.2, RV4109.3, TP4109.1, U101.6
unnamed: R4111.1, RV4109.1
unnamed: R4204.1, TH3.2, TP4204.1, U102.2, U120.3
unnamed: R4204.2, RV4202.1
unnamed: R4205.1, R4206.2, U102.3
unnamed: R4207.1, RV4201.1
unnamed: R4207.2, R4208.1, U120.2
unnamed: R4208.2, R4210.1, U102.7
unnamed: R4210.2, RV4209.2, RV4209.3, TP4209.1, U102.6
unnamed: R4211.1, RV4209.1
unnamed: R4304.1, TH4.2, TP4304.1, U103.2, U120.5
unnamed: R4304.2, RV4302.1
unnamed: R4305.1, R4306.2, U103.3
unnamed: R4307.1, RV4301.1
unnamed: R4307.2, R4308.1, U120.6
unnamed: R4308.2, R4310.1, U103.7
unnamed: R4310.2, RV4309.2, RV4309.3, TP4309.1, U103.6
unnamed: R4311.1, RV4309.1
unnamed: TH1.1, U100.1, U100.5
unnamed: TH2.1, U101.1, U101.5
unnamed: TH3.1, U102.1, U102.5
unnamed: TH4.1, U103.1, U103.5

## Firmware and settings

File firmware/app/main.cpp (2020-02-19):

/*
   Copyright (C) 2019, Kai Raphahn

   Licensed under the Apache License, Version 2.0 (the "License");
   you may not use this file except in compliance with the License.
   You may obtain a copy of the License at

       http://www.apache.org/licenses/LICENSE-2.0

   Unless required by applicable law or agreed to in writing, software
   distributed under the License is distributed on an "AS IS" BASIS,
   WITHOUT WARRANTIES OR CONDITIONS OF ANY KIND, either express or implied.
   See the License for the specific language governing permissions and
   limitations under the License.
*/

#include <Arduino.h>
#include <SPI.h>

#include <settings.h>
#include <dout.h>
#include <button.h>
#include <display.h>
#include <temperature.h>

#include <loop.h>
#include <utils.h>
#include <conf.h>


// Declarations
// -=-=-=-=-=-=-=-=-=-=-=-=-=-=-=-=-=-=-=-=

void handleISR1();
void handleISR2();
void print_channel();

void setup();
void loop();


// Manager
Config::Manager* config = new Config::Manager();
Loop* looper = new Loop();
SPIClass* spi = new SPIClass();


// Devices
DOut* led1 = new DOut(1, PIN_LED1);
Button::Manager* button1 = new Button::Manager(1, PIN_BUTTON1);
Button::Manager* button2 = new Button::Manager(2, PIN_BUTTON2);
Display* display = new Display(spi, PIN_CS1, PIN_DISPLAY);
Temperature::Manager* temperature = new Temperature::Manager(spi, PIN_CS2);


// Variables
Button::Click click1 = Button::Click::NONE;
Button::Click click2 = Button::Click::NONE;


// Implemnatation

void handleISR1()
{
    button1->handleISR();
}


void handleISR2()
{
    button2->handleISR();
}


void print_channel()
{
    Temperature::Channel* channel = temperature->current();

    if (channel->type == Temperature::Type::NONE) {
        return;
    }

    if (channel->type == Temperature::Type::DATA) {
        display->write(2, "%u: %u", channel->num, channel->data);
    }

    if (channel->type == Temperature::Type::VOLTAGE) {
        display->write(2, "%u: %5.3f V", channel->num, channel->value);
    }

    if (channel->type == Temperature::Type::RTD) {
        display->write(2, "%u: %5.3f C", channel->num, channel->value);
    }

    if (channel->type == Temperature::Type::PTC10) {
        display->write(2, "%u: %5.3f C", channel->num, channel->value);
    }

    if (channel->type == Temperature::Type::PTC100) {
        display->write(2, "%u: %5.3f C", channel->num, channel->value);
    }
}


void setup()
{
    Serial.begin(115200);
    delay(3000);

    looper->add_device(led1);
    looper->add_device(button1);
    looper->add_device(button2);
    looper->add_device(display);
    looper->add_device(temperature);

    button1->setISR(handleISR1);
    button2->setISR(handleISR2);

    config->setup();
    config->read();

    bool check = config->verify();

    if (check == false) {
        config->reset();
        config->set_channel(0, (uint8_t)Temperature::Type::RTD);
        config->set_channel(1, (uint8_t)Temperature::Type::PTC10);
        config->set_channel(2, (uint8_t)Temperature::Type::PTC100);
        config->set_delay(20);
        config->set_wlan(0, "TEST-SSID", "TEST-PASS");
        config->write();
    }

    config->print();

    for (int i = 0; i < TEMP_CHANNELS; ++i) {
        temperature->add_channel(i, (Temperature::Type)config->get_channel(i));
    }

    DEBUG_MSG("SPI: SCLK %d, MISO %d, MOSI %d\n", PIN_SCLK, PIN_MISO, PIN_MOSI);


#ifdef ESP32
    spi->begin(PIN_SCLK, PIN_MISO, PIN_MOSI, PIN_NONE);
#else
    spi->pins(PIN_SCLK, PIN_MISO, PIN_MOSI, PIN_NONE);
    spi->begin();
#endif // ESP32

    looper->set_counter(0, 10);
    looper->set_counter(1, config->data()->measure_delay);
    looper->set_counter(2, 100);
    looper->setup();
}


void loop()
{
    looper->start_loop();
    temperature->set_measure(false);

    click1 = button1->click();
    click2 = button2->click();

    if (click1 == Button::Click::SINGLE) {
        temperature->next();
        print_channel();
        looper->reset_counter(2);
        button1->reset();
    }

    if (click2 == Button::Click::SINGLE) {
        temperature->prev();
        print_channel();
        looper->reset_counter(2);
        button2->reset();
    }


    if (looper->counter() == 0) {
        led1->on();
    }

    if (looper->counter() == 10) {
        display->clear();
        display->write(1, "Start");
        temperature->set_measure(true);
    }

    if (looper->counter() == 20) {
        display->write(1, "Measure");

        looper->activate();
        temperature->set_measure(true);
    }

    if (looper->counter() == 30) {
        print_channel();
    }

    if (looper->number(0) == 10) {
        led1->toggle();
    }

    if (looper->number(2) == 100) {
        temperature->next();
        print_channel();
    }

    if (looper->number(1) == config->data()->measure_delay) {
        temperature->set_measure(true);
    }

    looper->end_loop();
}

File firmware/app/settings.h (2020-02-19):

/*
   Copyright (C) 2019, Kai Raphahn

   Licensed under the Apache License, Version 2.0 (the "License");
   you may not use this file except in compliance with the License.
   You may obtain a copy of the License at

       http://www.apache.org/licenses/LICENSE-2.0

   Unless required by applicable law or agreed to in writing, software
   distributed under the License is distributed on an "AS IS" BASIS,
   WITHOUT WARRANTIES OR CONDITIONS OF ANY KIND, either express or implied.
   See the License for the specific language governing permissions and
   limitations under the License.
*/

#ifndef CONFIG_H_INCLUDED
#define CONFIG_H_INCLUDED

#ifdef ESP32
#define PIN_LED1        2  // internal LED1
#define PIN_DISPLAY     15 // display switch
#define PIN_BUTTON1     23 // push button 1
#define PIN_BUTTON2     22 // push button 2
#define PIN_CS1         21 // SPI chip select 1, Display
#define PIN_CS2         4  // SPI chip select 2, Temperature

#define PIN_SCLK        19 // SPI clock
#define PIN_MISO        18 // SPI MISO
#define PIN_MOSI        5  // SPI MOSI
#define PIN_NONE        14 // SPI CS, not used
#endif // ESP32

#ifdef ESP8266
#define PIN_LED1        16 // D0, internal LED1
#define PIN_BUTTON1     4  // D2, push button 1
#define PIN_BUTTON2     5  // D1, push button 2
#define PIN_CS1         2  // D4, SPI chip select 1, Display
#define PIN_CS2         15 // D8, SPI chip select 2, Temperature

#define PIN_SCLK        14 // D5, SPI clock
#define PIN_MISO        12 // D6, SPI MISO
#define PIN_MOSI        13 // D7, SPI MOSI
#define PIN_NONE        0  // D3, SPI CS, not used
#endif // ESP8266

#define DISPLAY_DIGITS  16

#define CLICK_SINGLE    50
#define CLICK_HOLD      3000

#define TEMP_CHANNELS   8
#define TEMP_ARRAY      240
#define TEMP_LIMIT      4095 // max value of adc, everything above is suspect

#define LOOP_WAIT       100

#define WLAN_SSID       32
#define WLAN_PASS       64

#define DEFAULT_DELAY   120
#define CHANNEL_LOOPS   8

#ifdef DEBUG_ESP_PORT
#define DEBUG_MSG(...) DEBUG_ESP_PORT.printf( __VA_ARGS__ )
#endif // DEBUG_ESP_PORT

#ifdef DEBUG_ESP32_PORT
#define DEBUG_MSG(...) DEBUG_ESP32_PORT.printf( __VA_ARGS__ )
#endif // DEBUG_ESP32_PORT

#if !defined(DEBUG_ESP_PORT) && !defined(DEBUG_ESP32_PORT)
#define DEBUG_MSG(...)
#endif

#endif // CONFIG_H_INCLUDED

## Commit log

2019-08-28 feat: Create Scheme
    Add KiCad data
    Issue #1
    [ADC.sch, BBSensor.kicad_pcb, BBSensor.sch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]
2019-08-28 feat: Create Scheme
    add Temperature1
    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
    [BBSensor.sch, Temperature1.sch]
2019-08-28 feat: Create Scheme
    add Temperatures
    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
    [ADC.sch, BBSensor.kicad_pcb, BBSensor.sch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]
2019-08-29 feat: Create Scheme
    switch 4-8 with normal sensors, add test PCB
    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
    [ADC.sch, BBSensor.kicad_pcb, BBSensor.sch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]
2019-08-29 feat: Firmware: Create groundwork for the firmware
    add first test code and sketch
    Issue #3
    [blink.ino]
2019-08-29 feat: Firmware: Create groundwork for the firmware
    add template for commit message
    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
2019-08-29 feat: Firmware: Create groundwork for the firmware
    update compile message
    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
    [blink.ino]
2019-08-29 feat: Firmware: Create groundwork for the firmware
    move sketch file for arduino
    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
    [blink.ino]
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2019-08-29 feat: Create Scheme
    redo voltage amps for Pt100 with Testpoints
    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
    [BBSensor.kicad_pcb, Temperature1.sch, Temperature2.sch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]
2019-08-30 feat: Create PCB
    Create and fix PCB
    Issue #2
    [ADC.sch, BBSensor.kicad_pcb, BBSensor.sch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]
2019-08-30 feat: Create PCB
    fix rights
    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
    [ADC.sch, BBSensor.kicad_pcb, BBSensor.sch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]
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2019-08-30 feat: Create groundwork for the firmware
    prepare Code::Blocks projects
    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
    [main.cpp]
2019-08-30 feat: Create groundwork for the firmware
    try to get Codeblocks working....
    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
2019-08-30 feat: Create groundwork for the firmware
    switch to CMake instead of Code::Blocks
    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
    [ADC.sch, BBSensor.kicad_pcb, BBSensor.sch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]
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2019-08-30 feat: Create groundwork for the firmware
    remove config.cmake, replace with template
    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
2019-08-30 feat: Create groundwork for the firmware
    prepare Core build lib
    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
2019-08-30 feat: Create groundwork for the firmware
    ditch cmake, use Makefiles directly....
    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
2019-08-31 feat: Create groundwork for the firmware
    finally a working build
    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
2019-08-31 feat: Create groundwork for the firmware
    use cygwin make and tools as Makefile
    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
2019-08-31 feat: Create groundwork for the firmware
    make makefile more simple
    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
2019-08-31 feat: Create groundwork for the firmware
    add help for makefiles
    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
2019-09-01 feat: Create groundwork for the firmware
    make Code::Blocks work again with Makefiles
    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
2019-09-01 feat: Create groundwork for the firmware
    add more debug info
    make echo custom
    prepare upload
    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
2019-09-01 feat: Create groundwork for the firmware
    add logging for debug of build process
    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
2019-09-02 feat: Split Display SPI converter from main PCB
    move prepare
    Issue #13
    [ADC.sch, BBSensor.kicad_pcb, BBSensor.sch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]
2019-09-02 feat: Split Display SPI converter from main PCB
    split display
    add new pcb
    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
    [ADC.sch, BBSensor.kicad_pcb, BBSensor.sch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]
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2019-09-02 feat: Split Display SPI converter from main PCB
    shrink display connector
    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
    [Display.kicad_pcb, Display.sch]
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2019-09-04 feat: General PCB improvements
    redo PCB, shrink it to 153 mm
    generate PCB VRML
    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
    [BBSensor.kicad_pcb]
2019-09-04 feat: General PCB improvements
    add CAD
    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
    [BBSensor.FCStd]
2019-09-05 feat: General PCB improvements
    switch Power inlet
    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
    [BBSensor.kicad_pcb, Power.sch]
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2019-09-08 feat: General PCB improvements
    add seperate Pt100 schematic and PCB
    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
    [Pt100.kicad_pcb, Pt100.sch]
2019-09-08 feat: General PCB improvements
    add Pt100 CAD
    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
    [Pt100.FCStd]
2019-09-08 feat: General PCB improvements
    use old stuff
    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
    [Pt100.kicad_pcb]
2019-09-09 feat: General PCB improvements
    rename to Pt100
    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
    [RTD.kicad_pcb, RTD.sch]
2019-09-09 feat: General PCB improvements
    rename folder
    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
    [RTD.kicad_pcb, RTD.sch]
2019-09-09 feat: General PCB improvements
    redo Scheme
    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
    [RTD.kicad_pcb, RTD.sch]
2019-09-09 feat: General PCB improvements
    add PTC sensor
    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
    [PTC.kicad_pcb, PTC.sch]
2019-09-09 feat: General PCB improvements
    rename Pt100, add PTC
    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
    [RTC.FCStd, RTD.FCStd]
2019-09-09 feat: General PCB improvements
    redo PTC pcb
    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
    [PTC.kicad_pcb, PTC.sch]
2019-09-09 feat: General PCB improvements
    reorder
    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
    [ADC.sch, BBSensor.FCStd, BBSensor.kicad_pcb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]
2019-09-09 feat: General PCB improvements
    rename
    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
    [ADC.sch, BBSensor.FCStd, BBSensor.kicad_pcb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]
2019-09-09 feat: General PCB improvements
    add gerber files
    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
    [PTC-B_Cu.gbl, PTC-B_Mask.gbs, PTC-B_SilkS.gbo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]
2019-09-09 feat: General PCB improvements
    add plot data for PTC
    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
    [PTC-B_Cu.gbl, PTC-B_Mask.gbs, PTC-B_SilkS.gbo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]
2019-09-09 feat: General PCB improvements
    add gerber and pdf files
    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
    [Display-B_Cu.gbl, Display-B_Mask.gbs, Display-B_SilkS.gbo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]
2019-09-09 feat: General PCB improvements
    add plot for Sensor
    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
    [BBSensor-B_Cu.gbl, BBSensor-B_Mask.gbs, BBSensor-B_SilkS.gbo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]
2019-09-09 feat: General PCB improvements
    add gerbv file
    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
    [Display-B_Cu.gbl, Display-B_Mask.gbs, Display-B_SilkS.gbo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]
2019-09-09 feat: General PCB improvements
    redo gerber, add view file
    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
    [BBSensor-B_Cu.gbl, BBSensor-B_Mask.gbs, BBSensor-B_SilkS.gbo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]
2019-09-10 feat: General PCB improvements
    add Mini PCB
    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
    [ADC.sch, BBMini.kicad_pcb, BBMini.sch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]
2019-09-10 feat: General PCB improvements
    add Mini PCB (needs to be redone for RM2015L
    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
    [BBMini-B_Cu.gbl, BBMini-B_Mask.gbs, BBMini-Edge_Cuts.gm1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]
2019-09-11 feat: General PCB improvements
    reddo with RM2015L pcb
    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
    [ADC.sch, BBMini.FCStd, BBMini.kicad_pcb]
2019-09-11 feat: General PCB improvements
    finalize front, need to move mountings
    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
    [BBMini.FCStd, BBMini.kicad_pcb]
2019-09-12 feat: General PCB improvements
    redo pcb with more mountings, fit better to panels
    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
    [ADC.sch, BBMini.FCStd, BBMini.kicad_pcb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]
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2019-09-13 feat: Add CAD for assembly
    finish Panel
    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
    [Panel_Back.dxf]
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2019-09-16 feat: General PCB improvements
    fix Display, add BOM
    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
    [ADC.sch, BBMini.kicad_pcb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]
2019-09-16 feat: General PCB improvements
    redo BBMini
    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
    [BBMini-B_Cu.gbl, BBMini-B_Mask.gbs, BBMini-Edge_Cuts.gm1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]
2019-09-16 feat: General PCB improvements
    redo Display
    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
    [Display-B_Cu.gbl, Display-B_Mask.gbs, Display-Edge_Cuts.gm1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]
2019-09-16 feat: General PCB improvements
    redo PTC
    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
    [PTC-B_Cu.gbl, PTC-B_Mask.gbs, PTC-Edge_Cuts.gm1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]
2019-09-16 feat: General PCB improvements
    redo RTD PCB
    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
    [RTD-B_Cu.gbl, RTD-B_Mask.gbs, RTD-Edge_Cuts.gm1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]
2019-09-16 feat: General PCB improvements
    add BOM
    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
    [BOM.ods]
2019-09-17 feat: Add CAD for assembly
    finish CAD
    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
    [BBMini.FCStd]
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2019-09-18 feat: Firmware - Make basics work
    rename sensor to main
    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
    [main.cpp]
2019-09-18 feat: Firmware - Make basics work
    add virtual device for devices, reorder includes
    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
    [main.cpp]
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2019-09-19 feat: Firmware - Make basics work
    redo dependency handling
    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
    [main.cpp]
2019-09-19 feat: Firmware - Make basics work
    add SPI
    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
    [blink.ino, main.cpp]
2019-09-20 feat: Firmware - Make basics work
    switch PINs for SPI Interface
    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
    [BBMini.kicad_pcb, ESP8266.sch]
2019-09-20 feat: Firmware - Make basics work
    use new SPI pins, redo pin naming for config
    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
    [main.cpp]
2019-09-20 feat: Firmware - Make basics work
    count loops
    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
    [main.cpp]
2019-09-20 feat: Firmware - Make basics work
    add mini loop manager, add spi to Hardware
    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
    [main.cpp]
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2019-09-20 feat: Firmware - Make basics work
    * add button class
    * set button interrupts for rising and falling
    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
    [main.cpp]
2019-09-20 feat: Firmware - Make basics work
    * change ISR to CHANGE
    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
    [main.cpp]
2019-09-22 feat: Firmware - Make basics work
    try to get click button parsing working
    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
    [main.cpp]
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2019-09-23 feat: Firmware - Make basics work
    add second push button
    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
    [BBMini.kicad_pcb, ESP8266.sch]
2019-09-23 feat: Firmware - Make basics work
    * add second button
    * add button number to click
    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
    [main.cpp]
2019-09-23 feat: Firmware - Make basics work
    reorder source
    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
    [main.cpp]
2019-09-23 feat: Firmware - Make basics work
    * prepare display and temperature
    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
    [display.cpp, main.cpp]
2019-09-23 feat: Firmware - Make basics work
    * prepare Display and Temperature classes
    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
    [display.cpp, settings.h, temperature.cpp]
2019-09-23 feat: Firmware - Make basics work
    * add channel for temperatures
    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
    [settings.h, temperature.cpp]
2019-09-23 feat: Firmware - Make basics work
    * redo global Makefile
    * add Wifi Lib
    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
    [blink.ino, main.cpp]
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2019-09-24 feat: BBMini2 - experimental ESP8266 PCB (SMD)
    * add PCB for experimental version
    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
    [ADC.sch, BBMini2.kicad_pcb, BBMini2.sch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]
2019-09-25 feat: BBMini2 - experimental ESP8266 PCB (SMD)
    try to use ESP-12F
    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
    [ADC.sch, BBMini2.sch, Display.sch]
2019-09-25 feat: BBMini2 - experimental ESP8266 PCB (SMD)
    * update pcb
    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
    [ADC.sch, BBMini2.kicad_pcb, BBMini2.sch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]
2019-09-25 feat: BBMini2 - experimental ESP8266 PCB (SMD)
    make PCB variations
    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
    [BBMini2.kicad_pcb, BBMini2.sch, ESP8266EX.sch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]
2019-09-26 feat: BBMini2 - experimental ESP8266 PCB (SMD)
    * shrink PCB, switch components
    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
    [BBMini2.kicad_pcb, ESP8266EX.sch, IO.sch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]
2019-09-27 feat: BBMini2 - experimental ESP8266 PCB (SMD)
    make everything smaller
    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
    [BBMini2.kicad_pcb, ESP8266EX.sch, IO.sch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]
2019-09-27 feat: BBMini2 - experimental ESP8266 PCB (SMD)
    * add nee stuff
    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
    [BBMini2.kicad_pcb, BBMini2.sch, Power.sch]
2019-09-27 feat: BBMini2 - experimental ESP8266 PCB (SMD)
    * add reference_
    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
    [BBMini2.kicad_pcb, BBMini2.sch, IO.sch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]
2019-09-28 feat: Firmware: Add Display
    * fix broken code
    * use two buttons
    * prepare Display SPI
    Issue #5
    [ADC.sch, BBMini.sch, Display.sch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]
2019-09-28 feat: Firmware: Add Display
    * use correct buttons and LED PINs in PCB
    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
    [BBMini.kicad_pcb]
2019-09-29 feat: BBMini2 - experimental ESP8266 PCB (SMD)
    * redo Mini2
    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
    [BBMini2.kicad_pcb, BBMini2.sch, ESP8266EX.sch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]
2019-09-29 feat: Firmware: Add Display
    * make SPI work, need to reroute CS Pins
    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
    [ADC.sch, BBMini.sch, Display.sch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]
2019-09-29 feat: Firmware: Add Display
    * update Mini PCB with current hardware implementation
    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
    [BBMini.kicad_pcb]
2019-09-29 feat: Firmware: Add Display
    * cleanup transfer code, convert to device code as extra SPI
    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
    [device.cpp, display.cpp, main.cpp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]
2019-09-30 feat: Firmware: Add Display
    * shrink pcb
    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
    [BBMini.kicad_pcb]
2019-09-30 feat: Firmware: Add Display
    * finish shrinking
    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
    [BBMini.kicad_pcb]
2019-09-30 feat: BBMini2 - experimental ESP8266 PCB (SMD)
    * update Mini2 with current SDK
    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
    [BBMini2.kicad_pcb, BBMini2.sch, ESP8266EX.sch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]
2019-10-01 feat: BBMini2 - experimental ESP8266 PCB (SMD)
    * shrink pcb, add cad
    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
    [BBMini2.kicad_pcb, Power.sch]
2019-10-01 feat: BBMini2 - experimental ESP8266 PCB (SMD)
    * redo PCB, add CAD
    * make space for Display
    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
    [BBMini2.kicad_pcb]
2019-10-04 feat: BBMini2 - experimental ESP8266 PCB (SMD)
    * finalize new Case (experimental)
    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
    [BBMini2.kicad_pcb]
2019-10-05 feat: Firmware: Add Display
    * use CS signals correctly
    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
    [device.cpp, display.cpp, main.cpp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]
2019-10-05 feat: Firmware: Add Display
    * set two pins on
    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
    [main.cpp]
2019-10-06 feat: Firmware: Add Display
    * bits are now send correctly
    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
    [main.cpp]
2019-10-06 feat: Firmware: Add Display
    * redo debug output for SPI
    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
    [device.cpp, display.cpp]
2019-10-06 feat: Firmware: Add Display
    * start implementing Display init
    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
    [display.cpp, main.cpp]
2019-10-06 feat: Firmware: Add Display
    * add pin converter for Display
    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
    [device.cpp, display.cpp]
2019-10-08 feat: BBMini2 - experimental ESP8266 PCB (SMD)
    * add Display to Mini2
    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
    [BBMini2.kicad_pcb, ESP8266EX.sch, IO.sch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]
2019-10-09 feat: BBMini2 - experimental ESP8266 PCB (SMD)
    * add display to pcb
    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
    [BBMini2.kicad_pcb, ESP8266EX.sch, Power.sch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]
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2019-10-10 feat: BBMini2 - experimental ESP8266 PCB (SMD)
    * redo CAD, switch LEDs
    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
    [BBMini2.kicad_pcb, ESP8266EX.sch, Mini2.FCStd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]
2019-10-10 feat: BBMini2 - experimental ESP8266 PCB (SMD)
    * implement Case, add 9 V block holder
    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
    [9V_Case.step, 9vcase.STL, BBMini2.kicad_pcb]
2019-10-13 feat: Firmware: Add Display
    fix bugs, need to redo the signal transfer... its too complicated
    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
    [display.cpp, settings.h]
2019-10-13 feat: Firmware: Add Display
    * simpliyfy pin assignment, fix potential bug
    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
    [device.cpp, display.cpp]
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2019-10-14 feat: Version 3: Experimental PCB with only one ADC and multiplexer
    * prepare PCB
    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
    [BBMini3.kicad_pcb, BBMini3.sch, ESP8266EX.sch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]
2019-10-15 feat: Version 3: Experimental PCB with only one ADC and multiplexer
    implemenrt multiplexer
    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
    [BBMini3.sch, ESP8266EX.sch, Power.sch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]
2019-10-15 feat: Version 3: Experimental PCB with only one ADC and multiplexer
    finish PCB for multiplexer model
    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
    [BBMini3.sch, ESP8266EX.sch, Power.sch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]
2019-10-16 feat: Version 3: Experimental PCB with only one ADC and multiplexer
    shrink stuff, start pcb
    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
    [BBMini3.kicad_pcb, ESP8266EX.sch, Power.sch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]
2019-10-16 feat: Version 3: Experimental PCB with only one ADC and multiplexer
    * add new PCB
    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
    [BBMini3.kicad_pcb, Serial.sch]
2019-10-17 feat: Version 3: Experimental PCB with only one ADC and multiplexer
    more work on pcb
    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
    [BBMini3.kicad_pcb]
2019-10-27 feat: Firmware: Add Display
    fix signals, make display work
    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
    [device.cpp, display.cpp, main.cpp]
2019-10-27 feat: Firmware: Add Display
    make lines work
    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
    [display.cpp, main.cpp]
2019-10-27 feat: Firmware: Add Display
    Display is done
    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
    [display.cpp, main.cpp]
2019-10-27 feat: Firmware: Add Display
    readd signal class so I can store signals
    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
    [display.cpp]
2019-10-28 feat: Firmware: Add Display
    switch from class to stucture for Signals
    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
    [display.cpp, main.cpp]
2019-10-29 feat: Firmware: Add Display
    cleanup debug settings
    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
    [device.cpp]
2019-11-03 feat: Firmware: Add Display
    fix some comments
    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
    [settings.h]
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2019-11-03 feat: Firmware: Read temperatures
    fix timing when display debug is disabled
    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
    [device.cpp, display.cpp, temperature.cpp]
2019-11-04 feat: Firmware: Read temperatures
    redo SPI handling via lists and parse results
    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
    [device.cpp, display.cpp, temperature.cpp]
2019-11-04 feat: Firmware: Read temperatures
    parse answer, fix commands
    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
    [temperature.cpp]
2019-11-05 feat: Firmware: Read temperatures
    move channel processing into function
    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
    [temperature.cpp]
2019-11-05 feat: Firmware: Read temperatures
    siwtch from int and byte to uint8_t/uint16_t
    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
    [device.cpp, display.cpp]
2019-11-10 feat: Firmware: Read temperatures
    make temperature work
    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
    [main.cpp, settings.h, temperature.cpp]
2019-11-16 feat: Firmware: Convert temperatures
    add better timeout handling
    Issue #27
    [device.cpp, temperature.cpp]
2019-11-16 feat: Firmware: Convert Temperatures
    prepare add tables with temperatures
    add sheet with voltages
    read two temps from main
    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
    [ADC.ods]
2019-11-16 feat: Firmware: Convert Temperatures
    redo channel setup
    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
    [main.cpp, settings.h, temperature.cpp]
2019-11-16 feat: Firmware: Convert Temperatures
    convert to voltage
    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
    [main.cpp]
2019-11-16 feat: Firmware: Convert Temperatures
    Show voltage measures
    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
    [main.cpp]
2019-11-17 feat: Firmware: Read Config from EEPROM
    read and store config
    Issue #28
    [main.cpp, settings.h]
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2019-11-23 feat: Firmware: Read Config from EEPROM
    implement crc check
    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
    [main.cpp]
2019-11-24 feat: Firmware: Read Config from EEPROM
    add Namespace for Temperature
    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
    [main.cpp, temperature.cpp]
2019-11-24 feat: Firmware: Read Config from EEPROM
    cleanup defines
    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
    [settings.h, temperature.cpp]
2019-11-24 feat: Firmware: Read Config from EEPROM
    set config
    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
    [main.cpp]
2019-11-24 feat: Firmware: Read Config from EEPROM
    replace std with low level stuff
    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
    [device.cpp, main.cpp, settings.h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]
2019-11-24 feat: Firmware: Read Config from EEPROM
    fix channel clearing
    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
    [temperature.cpp]
2019-11-24 feat: Firmware: Read Config from EEPROM
    use config
    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
    [main.cpp, temperature.cpp]
2019-11-24 feat: Firmware: Read Config from EEPROM
    tune main
    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
    [main.cpp, temperature.cpp]
2019-11-24 feat: Firmware: Read Config from EEPROM
    fine tune output
    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
    [main.cpp, temperature.cpp]
2019-11-24 feat: Firmware: Read Config from EEPROM
    finish config
    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
    [main.cpp]
2019-11-24 feat Firmware: Convert Temperatures
    fix printing
    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
    [display.cpp, main.cpp]
2019-11-24 feat Firmware: Convert Temperatures
    replace string
    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
    [display.cpp]
2019-11-24 feat Firmware: Convert Temperatures
    improve display write
    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
    [display.cpp, main.cpp]
2019-11-25 feat: Firmware: Convert Temperatures
    remove more std stuff
    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
    [display.cpp]
2019-11-25 feat: Firmware: Convert Temperatures
    implement release flag
    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
    [display.cpp]
2019-11-25 feat: Firmware: Convert temperatures
    redo debug handling
    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
    [device.cpp, display.cpp]
2019-11-25 feat: Firmware: Convert Temperatures
    cleanup and simplify
    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
    [display.cpp, main.cpp, temperature.cpp]
2019-11-25 feat: Firmware: Convert Temperatures
    redo main
    implement button1 to toggle temps
    reset counter for prints
    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
    [main.cpp]
2019-11-26 feat: Firmware: Convert Temperatures
    make channel list dynamic and permanent
    implement next and last channel pointer
    shrink main loop complexity with last and next channel pointer
    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
    [main.cpp, temperature.cpp]
2019-11-27 feat: Firmware: Convert Temperatures
    remove toggle from main, move to temperature
    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
    [main.cpp, temperature.cpp]
2019-11-27 feat: Firmware: Convert Temperatures
    secure namespaces
    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
    [display.cpp, main.cpp]
2019-11-28 feat: Firmware: Code seperation into own lib
    rename src to app
    Issue #37
    [device.cpp, display.cpp]
2019-11-28 feat: Firmware: Code seperation into own lib
    move sketch
    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
    [blink.ino]
2019-11-28 feat: Firmware: Code seperation into own lib
    reset worktree
    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
    [device.cpp, display.cpp]
2019-11-28 feat: Firmware: Convert Temperatures
    remove utils
    fix missing ptc100
    switch to heap for cannels again
    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
    [device.cpp, display.cpp, main.cpp]
2019-11-28 feat: Firmware: Convert Temperatures
    some reorg
    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
    [main.cpp, settings.h]
2019-11-29 feat: Firmware: Convert Temperatures
    revert changes, refactor some stuff
    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
    [main.cpp, settings.h, temperature.cpp]
2019-12-01 feat Firmware: Convert Temperatures
    reset to last useable branch
    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
    [device.cpp, display.cpp]
2019-12-01 feat Firmware: Convert Temperatures
    purge debug.h
    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
    [device.cpp, display.cpp]
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2019-12-01 feat Firmware: Convert Temperatures
    reenable stuff
    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
    [main.cpp]
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2019-12-01 feat: Firmware: Use ESP32 Module
    make ESP32 compile (dunno if it works)
    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
    [device.cpp, display.cpp, temperature.cpp]
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2019-12-01 feat Firmware: Convert Temperatures
    fix temps
    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
    [main.cpp, temperature.cpp]
2019-12-01 feat Firmware: Convert Temperatures
    better toggle
    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
    [main.cpp, temperature.cpp]
2019-12-01 feat Firmware: Convert Temperatures
    repace substitutes
    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
    [main.cpp]
2019-12-01 feat Firmware: Convert Temperatures
    simplify toggle
    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
    [display.cpp, main.cpp, settings.h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]
2019-12-01 feat Firmware: Convert Temperatures
    make buttons work
    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
    [main.cpp, settings.h]
2019-12-02 feat: Firmware: Convert Temperatures
    change small stuff
    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
    [settings.h]
2019-12-02 feat: Firmware: Convert Temperatures
    cleanup and better output
    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
    [settings.h]
2019-12-02 feat: Firmware: Convert Temperatures
    add cyclic buffer functionality to channel
    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
    [temperature.cpp]
2019-12-03 feat: Hardware: Use ESP32 Module
    use ESP32 in BBSensor
    Issue #41
    [ADC.sch, BBMini32.kicad_pcb, BBMini32.sch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]
2019-12-04 feat: Firmware: Convert Temperatures
    add pinout defines for ESP32
    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
    [settings.h]
2019-12-08 feat Firmware: Convert Temperatures
    update schemes
    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
    [ADC.sch, BBMini.kicad_pcb, BBMini.sch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]
2019-12-08 feat: Firmware: Use ESP32 Module
    finish conversion to ESP32
    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
    [settings.h]
2019-12-11 feat: Firmware: Convert Temperatures
    remove channel, remove temperature from config
    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
    [main.cpp, temperature.cpp]
2019-12-11 feat: Firmware: Convert Temperatures
    reduce code overhead
    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
    [main.cpp, temperature.cpp]
2019-12-12 feat: Firmware: Convert Temperatures
    kill devices in old form
    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
    [device.cpp, display.cpp]
2019-12-12 feat: Firmware: Convert Temperatures
    chmod
    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
    [device.cpp, display.cpp]
2019-12-16 feat: Hardware: Use ESP32 Module
    redo Mini32 PCB
    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
    [ADC.sch, BBMini32.kicad_pcb, BBMini32.sch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]
2019-12-16 feat: Hardware: Use ESP32 Module
    remove crap
    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
    [Display.sch]
2019-12-17 feat: Hardware: Use ESP32 Module
    add new ESP32 module
    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
    [BBMini32.kicad_pcb, BBMini32.sch]
2019-12-17 feat: Hardware: Use ESP32 Module
    shrink PCB
    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
    [BBMini32.kicad_pcb, BBMini32.sch]
2019-12-23 feat: Hardware: Use ESP32 Module
    shrink board with SMD
    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
    [BBMini32.kicad_pcb, BBMini32.sch]
2019-12-23 feat Firmware: Convert Temperatures
    fix bug in channel activity
    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
    [temperature.cpp]
2019-12-23 feat Firmware: Convert Temperatures
    fix redorder of devices
    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
    [temperature.cpp]
2019-12-23 feat Firmware: Convert Temperatures
    fix button click
    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
    [main.cpp, temperature.cpp]
2019-12-23 feat: Replace Hardware class
    simplify hardware class
    Issue #45
    [main.cpp]
2019-12-23 feat Firmware: Convert Temperatures
    redorder button class with namespaces
    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
    [main.cpp, temperature.cpp]
2019-12-23 feat Firmware: Convert Temperatures
    move hardware stuff into looper
    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
    [main.cpp]
2019-12-24 feat Firmware: Convert Temperatures
    tweaks for measurement, add first log with results
    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
    [main.cpp, temperature.cpp]
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2019-12-25 feat: Hardware: Use ESP32 Module
    add Calibration matrix
    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
    [Calibration.ods]
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2020-02-17 feat: Use NPN to control display
    add NPN and code
    Issue #47
    [BBMini32.kicad_pcb, BBMini32.sch]
2020-02-18 feat: Use transistor to control display
    switch to PNP
    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
    [BBMini32.sch]
2020-02-19 feat: Split 5V rail from main PCB
    prepare
    Issue #51
    [DC.kicad_pcb, DC.sch]
2020-02-19 feat: Split 5V rail from main PCB
    split 5 V from PCB, remove old stuff
    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
    [9V_Case.step, 9vcase.STL, ADC.sch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]
2020-02-19 feat: Split 5V rail from main PCB
    prepare Mini32
    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
    [BBMini32.kicad_pcb, BBMini32.sch]
2020-02-20 feat: Split +5V rail from PCB
    redo normal PCB
    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
    [BBMini32.kicad_pcb, BBMini32.sch]
2020-02-20 feat: Split 5V rail from main PCB
    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
    [BBMini32-B_Cu.gbl, BBMini32-B_Mask.gbs, BBMini32-B_SilkS.gbo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]
2020-02-21 feat: Split 5V rail from main PCB
    shrink pcp, switch push buttons
    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
    [BBMini32-B_Cu.gbl, BBMini32-B_Mask.gbs, BBMini32-B_SilkS.gbo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]
2020-02-21 feat: Use transistor to control display
    redo
    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
    [DC-B_Cu.gbl, DC-B_Mask.gbs, DC-Edge_Cuts.gm1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]
2020-02-21 feat: Split 5V rail from main PCB
    redo PCB
    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
    [BBMini32-B_Cu.gbl, BBMini32-B_Mask.gbs, BBMini32-B_SilkS.gbo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]
2020-02-22 feat: Split 5V rail from main PCB
    redo PCB, start lid
    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
    [BBMini32.kicad_pcb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]
